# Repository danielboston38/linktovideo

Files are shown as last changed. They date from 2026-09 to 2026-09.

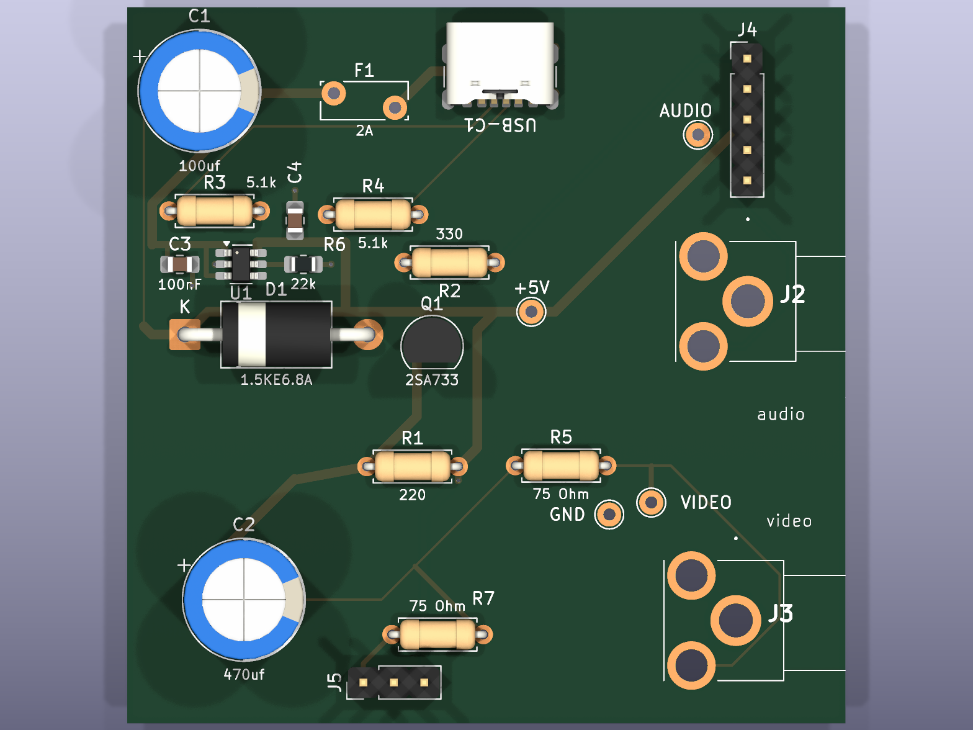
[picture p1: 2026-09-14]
pcb_top_final.png

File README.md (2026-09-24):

# Link to Video

A replacement for the RF modulator in the original Nintendo Entertainment System (NES-001). Drops into the stock RF module slot inside the shell and provides composite video and USB-C power in place of a part that fails by design.

<a href="https://certification.oshwa.org/us002842.html">
  OSHWA Certified Open Source Hardware UID US002842
</a>

> [!CAUTION]
> **Safety advisory for boards built before 2026-09-08.**
> On every board fabricated so far, the USB-C VBUS input reaches F1 through 9.06 mm of
> 0.2 mm-wide trace. That trace fails at a current well below F1's guaranteed trip
> current. If a fault occurs downstream, **F1 cannot protect the input trace on the
> board**.
> The defect has no effect on normal operation (48 °C, 17 mV drop). It is a
> fault-tolerance defect, not a wear-out defect: a board that works now will keep working.
> Commit [`247334c`](../../commit/247334c) corrects the layout. Reworking an affected
> board takes about 15 minutes.
>
> **→ Read the full advisory: [docs/SAFETY-ADVISORY-2026-09-vbus-trace-ampacity.md](docs/SAFETY-ADVISORY-2026-09-vbus-trace-ampacity.md)**

> **Renamed.** The first revision of this project was called **Kirby's New Dream**.
> From v2 on, it is **Link to Video**. Anything carrying the old name is the same
> project: the v1 board silkscreen, the 2026-07-16 PCBWay fab package, and older commits.
> The GitHub repository has been renamed too, and the old `kirbysnewdream` URL still
> redirects to it.

## Why this board exists

The NES-001's RF modulator already carries composite video, so this isn't about
adding an output the console lacks. It's about replacing a part that reliably
destroys itself.

Nintendo packed the modulator's regulator and RF stages into a sealed can with no
ventilation. It cooks its own electrolytics, they leak, and the electrolyte eats
the traces underneath. Across three NES-001 units on the author's bench, **all
three** had modulator failures from exactly this — including a Mitsumi unit that
looked pristine externally and had every capacitor leaking inside.

So the modulator is a consumable on a forty-year-old console, and the usual
options are to recap a corroded board or to fit an aftermarket board. This is the
second option, with the power input modernised to USB-C while the slot is open.

## Disclosure

This project's schematic design, debugging, and documentation were developed with the assistance of AI (Claude, by Anthropic). All hardware was hand-assembled, tested, and validated by the author. Use, review, and verify independently before building.

## Status

🟡 First prototype assembled and power-tested successfully (5V confirmed clean on rail, no protection trips). Video output path **does not work on v1 hardware** — traced to a schematic defect in which Q1's emitter node was shorted to the +5V rail (see Known Issues). Fixed in source; v1 boards need a rework.

<!-- Swap the line above for something like this once video's confirmed:
🟢 Fully validated — power and composite video both confirmed working on hardware.
-->

## Features

- USB-C power input (power only, no data lines)
- Composite video output
- Active overcurrent protection: TPS2553 eFuse with a ~1.18 A resistor-programmed limit, soft-start and thermal shutdown, and a polyfuse as backup
- Fits inside the original NES shell at the stock RF module location
- Bring-up test points for video, ground, +5 V and audio, labeled on the silkscreen
- Header that feeds an external 8-pin mini-DIN RGB connector (NESRGB)
- All resistor and capacitor values printed on the silkscreen (v1 had four identical, unlabeled axial footprints holding four different values, which led to three wrong-resistor build errors)
- 2-layer PCB, designed in KiCad

## Power path

```
USB-C  ──  F1 polyfuse  ──  U1 TPS2553 eFuse  ──  +5V rail  ──  J4.3 → NES
  VBUS      2.0A hold        ~1.18A limit          C1 100µF
            3.8A trip        soft-start            D1 TVS
            (backup)         thermal shutdown
```

F1 doesn't trip until 3.8 A, and the console only draws about 0.5–0.7 A, so on its
own F1 protects almost nothing. U1 does the real work. F1 is there in case the eFuse
fails short.

R6 on U1's ILIM pin sets the current limit. The relationship is
**inverse**: a larger resistor gives a *lower* limit.

| R6 | Limit (typ) |
|---|---|
| 15 kΩ | 1700 mA |
| 20 kΩ | 1295 mA |
| **22 kΩ (fitted)** | **~1180 mA** |
| 49.9 kΩ | 520 mA |
| 210 kΩ | 130 mA |

As a rule of thumb, I_OS(A) ≈ 25.9 / R6(kΩ), valid across TI's recommended range of
15 kΩ–232 kΩ.

U1's EN (pin 3) is active-high and tied to U1's own input, so the switch is always on.
FAULT (pin 4) is open-drain and left unconnected, since nobody can see an indicator
inside a closed NES shell. If you want a fault LED anyway, FAULT can sink 25 mA directly.

**Useful side effect: a reversed D1 is survivable.** D1 is a unidirectional TVS, so
installing it backwards puts a forward-biased diode straight across the 5 V rail.
Before the board had U1, that was a near-dead short, with only the polyfuse (which
takes seconds to react) in the way. Now the eFuse holds the current to ~1.18 A and
then shuts down thermally, so the mistake limits itself instead of destroying parts.

## Test points (v2)

The board has four through-hole test points (2.0 mm pad, 1.0 mm drill) for bring-up.
Each takes a 0.64 mm square header pin, so you can solder pins in and hang scope
grabbers off them.

The silkscreen shows only the signal name (`VIDEO`, `GND`, `+5V`, `AUDIO`), so you
can read the board without this table. The reference designators are on F.Fab, for
the fab drawings.

The first pass of v2 had this backwards: the signal names were on F.Fab, which never
reaches the physical board, so the silkscreen showed only `TP1`–`TP4`.

| TP  | Net | Location (mm) | Notes |
|-----|---|---|---|
| TP1 | `/VIDEO_OUT` | 62.0, 60.0 | Jack-side video, after C2 and the 75 Ω series resistor R5. This is what the TV sees. A high-impedance probe reads roughly double the terminated amplitude. |
| TP2 | `GND` | 58.5, 60.0 | Connects directly to the B.Cu ground pour. |
| TP3 | `/5V` | 52.0, 43.1 | On the protected 5 V trunk, downstream of F1 and the TPS2553. |
| TP4 | `/AUDIO_OUT` | 65.9, 28.35 | Audio pass-through between J4 pin 2 and J2. |

TP2 is just a convenience. The whole back layer is ground pour, so any B.Cu feature
works for a ground clip.

To probe the buffer itself rather than its output, go straight to Q1's emitter leg.
`Net-(Q1-E)` has no test point.

## RGB output (v2)

This board can feed the RGB connector for the [NESRGB](https://etim.net.au/nesrgb/)
board, which uses the 8-pin mini-DIN pinout of the Micomsoft XRGB-mini Framemeister.

The connector itself is **not** on this board. It comes with the NESRGB kit as a
panel-mount jack that is epoxied into a 12 mm hole in the shell. R/G/B run straight
from the NESRGB to that jack, and **J5** on this board supplies the other three pins:

| J5 pin | Net | mini-DIN pin | |
|---|---|---|---|
| 1 | `/RGB_VIDEO` | 3 | Composite video / sync, 75 Ω terminated |
| 2 | `GND` | 4 | |
| 3 | `/5V` | 5 | Downstream of the TPS2553, so it is current-limited |

Mini-DIN pins 1 and 2 are unconnected. Pins 6, 7 and 8 are Blue, Green and Red from
the NESRGB. The pinout carries no audio, so audio stays on the RCA jack. That was a
deliberate choice by Tim Worthington, to keep video noise out of the audio.

**Why R7 exists.** The output of the video buffer (`/VIDEO_BUF`, Q1's emitter
through C2) now feeds two outputs, and each needs its own 75 Ω source termination:
R5 for the RCA jack, R7 for the mini-DIN. A single shared resistor would put two
75 Ω loads in parallel whenever both cables were plugged in, halving the amplitude.

**One output at a time.** Composite and RGB are alternatives, and the design doesn't
target using both at once. Whichever cable is plugged in sees a correct 75 Ω source,
and the unused branch is just an unloaded stub.

If both cables are plugged in anyway, R7 still gives each output a correctly
terminated 75 Ω source, and the amplitude doesn't halve. The limit then becomes Q1's
drive, which is why **R1 is 220 Ω from v2**, down from the original 330 Ω.

In an ngspice simulation with 2 Vpp at the tap and both outputs terminated, the
follower clips the positive (white) peaks by 33 % at 330 Ω and by 11 % at 220 Ω.
With one output loaded (the supported mode), 220 Ω is clean and symmetric
(+0.439 / −0.447 V at the jack). These are simulated numbers, not bench
measurements, and driving both outputs is still unsupported.

## Hardware

- Designed in KiCad (schematic + PCB source included in this repo)
- Fabricated by PCBWay
- See [BOM.csv](./BOM.csv) for the full parts list

### Sponsored by PCBWay

The most recent fabrication run of this board — the 2026-08-26 package, ordered
**2026-08-27** — was
**sponsored by [PCBWay](https://www.pcbway.com/)**, who covered the manufacturing
of the boards this project is built and tested on. Thank you — having the fab
covered is what let this revision get made, populated and put on the bench rather
than staying a set of gerbers.

Those boards predate [`247334c`](../../commit/247334c), so like every board
fabricated so far they carry the `/raw_5v` trace-ampacity defect described in the
caution at the top of this file — see
[the safety advisory](docs/SAFETY-ADVISORY-2026-09-vbus-trace-ampacity.md).

PCBWay have been good to work with on the practical side too: the 2-layer,
1.6 mm FR4 board here is an unremarkable order for them, the gate-generated fab
package uploaded without any back-and-forth over the drill or layer files, and
they will run the four SMD lines (C3, R6, U1, USB-C1) as single-sided SMT while
leaving the through-hole parts to the bench — including sourcing the TPS2553
from LCSC, which DigiKey and Mouser have on a 112-day lead. See
[docs/pcbway-smd-assembly.md](./docs/pcbway-smd-assembly.md) for that workflow.

The project is also published on PCBWay's community site, with the same design
files and documentation as this repository:

**→ [Link to Video on PCBWay Community](https://www.pcbway.com/project/shareproject/Link_to_video_7f1f9279.html)**

The sponsorship covered fabrication only, and carries no editorial influence over
this documentation. The design remains [CERN-OHL-S v2](./LICENSE.txt) and
OSHWA-certified, free for anyone to study, modify, build and have made wherever
they like. The PCBWay-hosted copy is published under GPL v3 because their form
does not offer CERN-OHL-S — see [License](#license).

## Build Notes / Known Issues (v1)

- **Q1 emitter node shorted to +5 V (breaks video).** The rail clamps Q1's emitter,
  so C2 couples +5 V, not video, into R5/J3.

  The exact wiring differs between revisions. In the pre-v1.1 source in this
  repository, R1 had *both* ends on `/5V`. On the boards fabricated from the
  2026-07-16 gerbers, R1 pad 1 is on `/5V` and pad 2 is on a separate net with only C1.

  Root cause: an edit on 2026-07-04 deleted an R2 (110 Ω) from the schematic, and
  KiCad merged the two leftover collinear wire stubs into a single wire that tied the
  emitter node to `/5V`. The source is fixed as of v1.1. To rework an existing board,
  see [Q1 emitter rework (v1 boards)](#q1-emitter-rework-v1-boards).
- The mounting holes of the RCA jack are slightly asymmetric. This is cosmetic and
  doesn't affect the fit in the NES shell.
- The v1 silkscreen has no component values and no E/C/B markers for Q1.
  **v2 adds the values.** R1/R3/R4/R5/R7 share one footprint across four values, and
  on v1 that led to three wrong-resistor errors in R1: a 5.1 kΩ and an 820 Ω both
  went in before the correct value. Q1 pin markers are still missing.
- **VBUS input trace is undersized for its own fuse (all fabbed boards).** `/raw_5v`
  reaches F1 through 9.06 mm of 0.2 mm trace. At 2.22 A the trace heats past the glass
  transition of FR4, and at 2.83 A it chars. F1 (RHEF200) is guaranteed to hold up to
  2.0 A but only guaranteed to trip above 3.8 A, so in the 2.2–3.8 A window the trace
  can burn out before the fuse ever opens.

  Root cause: a gap in the netclass patterns. `/5V*`, `GND*` and `VBUS` were assigned
  the `Power` class (0.8 mm), but none of them matched the actual net name `/raw_5v`,
  so it fell through to `Default` (0.2 mm). DRC can't catch this, because it enforces
  the board's `min_track_width` (0.2 mm), not the netclass width. Commit `247334c`
  fixes the pattern and reroutes the trace at 0.8 mm.
  **Existing boards need a rework.** See
  [the safety advisory](docs/SAFETY-ADVISORY-2026-09-vbus-trace-ampacity.md).

- **D1 does not protect U1.** The installed TVS is a Littelfuse 1.5KE6.8A: stand-off
  5.80 V, breakdown 6.45–7.14 V at 10 mA, clamping 10.5 V at 144.8 A. The TPS2553's
  absolute maximum on IN and OUT is 7 V, which is where the TVS is only just starting
  to conduct. In a real surge, it lets the rail reach 10.5 V. D1 protects the console
  downstream, but not U1.

  Moving D1 wouldn't help, since both U1 pins share the same 7 V rating, and no
  avalanche TVS both clamps below 7 V and stands off USB-C's 5.5 V worst case. The
  real fix is a switch with a built-in overvoltage cutoff. That's a v3 change; v2
  ships with this gap.
- D1's symbol (`Diode:1.5KExxA`) labels its pins A1/A2 and shows no cathode, because
  KiCad uses the same pin names for the unidirectional and bidirectional variants of
  this part. Only the footprint's silkscreen band shows the polarity. The band is at
  the pad-1 (+5 V) end, which is correct, so go by the band when you assemble by hand.

### Q1 emitter rework (v1 boards)

This applies to boards fabricated from the 2026-07-16 gerbers, whose IPC netlist
reads:

- `/5V = J4.3, F1.1, R1.1, Q1.1, C2.1, D1.1`
- `Net-(C1-Pad1) = R1.2, C1.1`

That revision has two defects:

- The rail clamps Q1's emitter.
- C1 only reaches the rail through R1, so the bulk capacitor isn't decoupling the
  rail.

This procedure fixes both at once.

> [!CAUTION]
> **Do not power the board with Q1 installed until the cut is done.** This short kills transistors.
> With the emitter clamped at +5 V and the base at the NES video level, the B-E
> junction is forward-biased by 3–4 V. Q1 saturates into a collector tied straight to
> ground, and nothing limits the current: Q1 is a 150 mA part, and F1 won't trip until
> 3.8 A. Every power-up in that state can take out another transistor, which is
> probably how the first one died.

**Confirm the diagnosis before you cut.**

1. Disconnect the power.
2. Make sure the capacitors are discharged.
3. Put one meter lead on +5 V, at J4 pin 3 or at D1's K-marked lead.
4. Take the two measurements in the table. A defective board and a correct board
   give opposite results:

| Measurement | Defective board | Correctly wired |
|---|---|---|
| Q1 emitter → +5 V | **~0 Ω** | ~330 Ω (R1) |
| C1 **+** terminal → +5 V | **~330 Ω** (stranded behind R1) | ~0 Ω |

After the rework, the two readings swap.

To identify Q1's legs without relying on the TO-92 orientation, measure each leg:

- 0 Ω to GND: collector
- Continuity to J4 pin 1: base
- The remaining leg: emitter

Two tests look useful but aren't:

- **Emitter → J3 tip.** C2 blocks DC, so this reads open on every board.
- **C1 + → Q1 emitter.** This reads ~330 Ω on good and bad boards alike, because R1
  sits between these two points in both wirings.

With power on, the quickest check is the DC voltage at Q1's emitter: about 1.5–3 V
on a correct board, exactly the rail voltage on a shorted one.

**R1's left pad is a star point.** Three connections meet there:

- F1 (the source)
- The D1 + J4.3 branch (the load)
- Q1's emitter

The two incoming rail traces are *collinear*, so one cut severs both. That's why the
rework needs **two** jumpers, not one.

1. **Cut** the 0.8 mm trace that runs from R1's left pad toward the **upper
   left**, about 5–8 mm from the pad.

   Leave the trace coming in from the upper right alone. That one is Q1's emitter.

   Cut below the level of D1's cathode. Above that point, only one of the two
   overlapping traces is present, and you need to cut both.

2. **Install two jumpers.** Pull R1 first. Its right pad is much easier to solder
   when it's empty.

   The cut leaves three islands. Join all three into one rail:

   | Island | Pads |
   |---|---|
   | A | C1's **+** pad, R1's **right** pad |
   | B | F1 pad 1 (left pad, trace toward D1 — not the USB-C side) |
   | C | D1's cathode (K), J4 pin 3 |

   Any two wires that join all three islands will work. For example, with one wire
   per pad:
   - **C1+ → F1 pad 1** (~14 mm)
   - **R1's right pad → D1 cathode** (~25 mm)

3. **Install R1 = 300–330 Ω.** Double-check the part before it goes in. R1, R3, R4,
   R5 (and R7 on v2) share the same `R_Axial_DIN0207` footprint across four different
   values, and the v1 silkscreen shows none of them.

   At least one board ended up with a 5.1 kΩ from the R3/R4 pile in the R1 position.
   That gives ~0.6 mA of standing current instead of ~9 mA. The board looks plausible
   but produces no usable video.

4. **Check that R5 (75 Ω) is fitted.** Measure across its pads; you should see
   ~75 Ω. R5 has no parallel path in the circuit (C2 blocks DC on one side and the
   jack is open on the other), so this doubles as a sanity check of the meter.

5. **Install the transistor last.** If you power up before the cut is complete, Q1
   saturates and the rail dumps straight into ground with nothing limiting the
   current. See the caution above.

Before you power up, check with a meter:

- R1 left pad to D1 cathode: **open**
- R1 left pad to F1 pad 1: **~330 Ω**, through R1
- R1 left pad to Q1's emitter and to C2 pin 1: continuity
- D1 cathode to J4 pin 3 *and* to F1 pad 1: **~0 Ω**

With power on, Q1's emitter should sit at about 1.5–3 V. If it reads 5 V, the cut
didn't separate the traces.

## Video input biasing

Q1's base is DC-coupled directly to the NES video line, with no bias network. That's
deliberate, and it took a long bench session to work out why it works.

**The NES mainboard supplies a 1 kΩ pulldown on its video output pin.** It measures
0.999 kΩ in circuit, the same with the meter leads either way round, so it's a real
resistor and not a semiconductor junction. Q1's base sources about 46 µA, which that
1 kΩ soaks up at about 46 mV. The base can't float up, and Q1 can't cut off.

That's also why Nintendo's original modulator has no base pulldown. It's consistent
with the load Nintendo put on that pin, too: a 330 Ω series resistor into a
5.6 kΩ / 330 Ω divider, roughly 500 Ω in total. The NES is designed to drive a few
hundred ohms.

**So this board has no base pulldown and no input coupling capacitor.** If you
adapt this design for something other than an NES-001, measure that pin to ground
first, and if it reads open, add a pulldown (~47 kΩ).

**R2 (330 Ω) is not a bias resistor.** It sits in series between J4 pin 1 and Q1's
base, in the same position as Nintendo's own 330 Ω. Against Q1's ~21 kΩ base input
impedance it has almost no effect on the signal. Its job is to limit fault current
into the base-emitter junction, which is only rated for 5 V in reverse.

## Design checks

Beyond ERC and DRC, this project runs three more checks. The first two catch faults
this board actually shipped with. The third closes the gap between checking a board
and fabricating it.

### `tools/check_nets.py`

```
python3 tools/check_nets.py
```

The script exports the schematic netlist, reads the pad nets from the PCB, checks
that the two agree, and then asserts a set of invariants.

The most important invariant is that **Q1's emitter is not on any power net**.
That was the v1 fault: the emitter follower's output was tied to +5 V along with
J4.3, D1.1 and F1.1, so Q1 saturated into a grounded collector with nothing limiting
the current. Every power-up killed a transistor.

**ERC and DRC both passed on that board with no errors.** Neither can tell that a
net is *wrong*, only that it's internally consistent. That's why this script exists.

Run it before you generate a fab package. Gerbers carry no net information, so once
they're generated the mistake is invisible.

### `nes_power_video.kicad_dru`

Custom DRC rules for the geometric half of the problem:

- More clearance between the supply rails and the emitter and base nodes
- More clearance between the two USB-C configuration channels

These catch the same class of mistake when it shows up as adjacent copper in the
layout. They can't catch a wrong net assignment, because DRC knows nothing about
design intent. That's what the script above is for.

### `prefab-gate`

```
export KICAD_CLI=/Applications/KiCad/KiCad.app/Contents/MacOS/kicad-cli
prefab_gate package nes_power_video.kicad_pcb --out pcbway_production
```

**prefab-gate now lives in its own repository:
[danielboston38/prefab-gate](https://github.com/danielboston38/prefab-gate).**
It's a general-purpose KiCad tool with its own MIT license and users beyond this
project, so it moved out of this hardware repo.

You can install it any of these ways:

- As a KiCad plugin, through the Plugin and Content Manager
- As a Claude Code plugin: `/plugin marketplace add danielboston38/prefab-gate`
- By cloning the repository and running `scripts/prefab_gate.py` directly

The gate refuses to write a fab package unless the board passes both DRC with zone
refill *and* schematic parity. It hashes the board and the schematic after the
refill and checks them again right before publishing, so the package always
describes the board the gate actually verified. `manifest.json` records the result
along with every finding, including the cosmetic findings the gate waived.

To get the verdict without writing files, run `check` instead of `package`.

`pcbway_production/` isn't tracked in git, since the packages can be regenerated
from the board. The first two fab packages are still in the git history, at the
2026-07-07 and 2026-07-16 commits. The 2026-08-26 package for the sponsored run was
never committed, but its copper and outline gerbers have been checked byte-identical
to the board at [`f672f8d`](../../commit/f672f8d), and all 49 drill hits match.

When you order, generate a fresh fab package rather than reusing an old directory,
so the gate re-verifies the exact board you're paying for.

## Assembly

<!-- Add step-by-step or reference photos here once you've got a documented build process -->

See BOM.csv for the exact part values and footprints. Every component's sourcing
data lives in two places, and the two agree:

- The `Manufacturer`, `MPN`, `LCSC`, `Supplier Link` and `Datasheet` fields on the
  schematic symbol
- The matching columns in `BOM.csv`

Generic passives deliberately have no manufacturer part number. They carry a `Spec`
field instead (tolerance, rating, package), and any part that meets it will do. To
pull the fields straight from the schematic:

```
kicad-cli sch export bom --group-by '' \
    --fields 'Reference,Value,Manufacturer,MPN,LCSC,Datasheet,Supplier Link,Spec' \
    -o bom.csv nes_power_video.kicad_sch
```

The `Mount` column in `BOM.csv` marks each line `SMD` or `THT`, taken from the
footprint attributes on the board.

### Having PCBWay fit the SMD parts

Only four parts need reflow — C3, R6, U1 and USB-C1 — and all four are on the top
side. PCBWay can do those as single-sided SMT while you hand-solder the 15
through-hole parts. That way you skip the two hardest joints on the board (the
SOT-23-6 and the Type-C receptacle) without paying for full assembly.

`tools/pcbway_assembly.py` builds the SMD-only upload pair from a gate-generated fab
package. It takes the SMD/THT split from the board, not from a hand-maintained list:

```
python3 tools/pcbway_assembly.py nes_power_video.kicad_pcb pcbway_production/<timestamp>
```

Two things to know before you order:

- **U1 is out of stock at both DigiKey and Mouser** (112-day factory lead). LCSC has
  44,000, so tell PCBWay to source U1 from LCSC.
- **USB-C1 is Hybrid, not SMD.** Its four shell stakes are through-hole pads on the
  paste layer, and they must reflow pin-in-paste with everything else. Don't leave
  them dry.

As of v2, all four SMD lines (C3, R6, U1, USB-C1) are LCSC parts, so PCBWay can source
the whole assembly BOM from LCSC. For the full workflow, including what to upload and
what not to, see **[docs/pcbway-smd-assembly.md](./docs/pcbway-smd-assembly.md)**.

Key notes:
- D1 (zener/TVS): put the cathode (banded end) toward the VBUS/+5V side. From v2, the
  silkscreen shows the actual part, `1.5KE6.8A`. Earlier boards show KiCad's generic
  symbol name, `1.5KExxA`, which isn't an orderable part.
- Q1 (**2SA733**, PNP): with the flat side facing you and the leads down, the pins are
  Emitter-Collector-Base, left to right.
  This replaces the 2SA1015/KSA1015, **both of which are end of life** (checked 2026-08-29): MCC's
  `2SA1015-GR-AP` is stocked at Mouser but flagged End of Life, and every onsemi `KSA1015` reads
  Obsolete on DigiKey, available only through Rochester Electronics' last-time-buy channel. The
  2SA733 is in current production, shares the E-C-B pin order exactly so it drops straight in, and is
  a better part for a video buffer: f_T 190 MHz typ against the 2SA1015's 80 MHz, C_ob 2–3 pF, P_C
  750 mW, with the same V_CEO −50 V / I_C −150 mA / V_EBO −5 V — so R2 still guards the base-emitter
  junction exactly as before. Buy the UTC `2SA733L-P-T92-B` from LCSC (**C5310429**, ~$0.035).
  Rank P is hFE 200–400, which matches the ~46 µA base current measured on the bench, so the bias
  point does not move. DigiKey's Renesas 2SA733 is Rochester stock at $1.90 — same trap, different part.
- **Why not a 2N3906 or BC557?** Not for the reason you might assume. Electrically the 2N3906 is
  perfectly happy here — V_CEO −40 V, I_C −200 mA, f_T 250 MHz, V_EBO −5 V, hFE 100–300 at 10 mA,
  every figure with huge margin against a 5 V rail at ~9.3 mA. The problem is the middle pin. Per
  UTC's ordering tables, the 2N3906 is **E-B-C** and the 2SA733 is **E-C-B**: the 3906 puts *base* in
  the centre where this board wants *collector*. Turning the part around gives C-B-E — base is still
  in the middle, so no orientation fixes it and you would have to cross two leads. On a v3 layout the
  pin order is free and the 2N3906 becomes a fine choice; on this board it is not. Pin order is a
  manufacturer's choice rather than a standard, so check the datasheet of the exact brand you buy.
- R1 (220 Ω): Q1's emitter load. One end goes to +5 V and the other to the Q1 emitter /
  C2 node; both ends on +5 V is wrong. v2 dropped R1 from 300 Ω to 220 Ω for more
  drive current. Assuming ~1.3 V at the base, 300–330 Ω gives only ~6.2 mA at peak
  white, and the 150 Ω load needs ~6.7 mA. If you measure something other than ~1.3 V
  DC at J4 pin 1, recalculate R1.
- R2 (330 Ω): series resistor in the video input line, between J4 pin 1 and Q1's base. See [Video input biasing](#video-input-biasing).
- **Trim all through-hole leads flush.** The board sits in the RF module slot with
  shielding directly underneath, and long leads on the bottom side will short to the
  can. On the prototype, this caused an intermittent supply trip that only happened
  when the board moved.
- C2 (470 µF): not 100 µF. Into the 150 Ω load, 100 µF gives τ=15 ms against a
  16.7 ms field period, so the picture tilts from top to bottom. 470 µF gives τ=70 ms.
- F1 (polyfuse): it's fine for it to sit slightly off the PCB. That's normal for
  radial-lead parts, not a defect.

  **KiCad has no footprint for the Littelfuse RHEF series.** F1 borrows
  `Fuse:Fuse_Bourns_MF-RG300`: pads 5.24 mm center-to-center, with 1.01 mm drills. The
  RHEF200's 0.51 mm leads at 5.05 ±0.75 mm spacing fit easily. But the Bourns part is
  rated 3.0 A/5.1 A and the silkscreen outline shows *its* body, so treat the outline
  as a rough guide, not a clearance boundary. A proper RHEF200 footprint moves pad 2 by
  ~1.2 mm and needs a reroute, so that's a v3 change rather than a patch.

  **F1 stays a Littelfuse RHEF200 and is deliberately not an LCSC part.** It's
  through-hole, so it isn't on the SMD assembly BOM that PCBWay sources anyway, and
  the LCSC alternatives are worse where it matters:
  - Jinrui JK30-200 (C369104): I_max drops to 40 A, and the part is 15.2 mm tall.
  - JKSEMI JK16-200T (C5183874): LCSC lists it as through-hole, but its datasheet is
    titled *"JK16 Series Surface Mount PTC Devices"* and shows no land pattern, so its
    package is unconfirmed.

  If you need to reorder F1, get it from DigiKey or Mouser along with the Switchcraft
  RCA jacks, which LCSC can't supply either.
- USB-C1: GCT USB4125-GF-A-0190, SMD receptacle. Power-only, 6P, no data lines,
  48 V / 3 A, 20,000 mating cycles.

  **As of v2, this part replaces the GCT USB4970-00-A**, which LCSC doesn't stock (a
  search for that MPN turns up nothing). The USB4125 is a different GCT line that LCSC
  *does* stock (C5246813). The board already used its land pattern, so this is a
  sourcing change only, not a layout change.

  The footprint is `Connector_USB:USB_C_Receptacle_GCT_USB4125-xx-x-0190`. Its copper,
  silk, fab, courtyard and drills are byte-identical to the plain `USB4125-xx-x`
  variant the board used before; only the name, the descr field and the 3D model
  differ.

  Use the **-0190** variant. Its 1.90 mm shell stake pokes 0.30 mm through this 1.6 mm
  board and gives a fillet on the bottom side. The 1.00 mm stake (plain
  `USB4125-GF-A`, C3151650) doesn't make it through. LCSC stocks fewer of these than
  of the generic Chinese 6P parts, so order spares.
- U1 (TPS2553, SOT-23-6): pin 1 (marked by the dot on the package) is IN. The pins run
  IN, GND, EN down one side and OUT, ILIM, FAULT up the other. Order the plain
  TPS2553DBVR. The `-1` suffix is the latch-off variant, which needs a power cycle
  after every trip; the plain part retries automatically.
- C3 (100 nF, 0805): TI wants C3 as close to U1 pin 1 as the layout allows. It sits
  immediately to the left of U1.
- R6 (22k, 0805): sets the current limit. Check the table in
  [Power path](#power-path) before you change it.

## Certification

This project is **OSHWA-certified open source hardware**, UID **[US002842](https://certification.oshwa.org/us002842.html)**.

The certification confirms that the design files, schematics, PCB layout, bill of
materials and documentation in this repository:

- Are published under an OSI/FSF-approved open license
- Are complete enough for someone else to study, modify, manufacture and distribute
  the hardware

See the [OSHWA certification directory entry](https://certification.oshwa.org/us002842.html)
for the registered details.

The certification mark above,
[`certification-mark-US002842-stacked.svg`](./certification-mark-US002842-stacked.svg),
was issued by OSHWA for this UID. It applies only to this design and doesn't transfer
to derivatives; each derivative needs its own certification.

## License

Licensed under [CERN-OHL-S v2](./LICENSE.txt) (strongly reciprocal open hardware license). See [LICENSE](./LICENSE.txt).

**The PCBWay community copy is GPL v3.** PCBWay's project form doesn't offer
CERN-OHL-S, so the copy
[on their community site](https://www.pcbway.com/project/shareproject/Link_to_video_7f1f9279.html)
is licensed GPL v3. Same design, same files, two license grants: use whichever one
you received the design under. Both licenses are copyleft and both are on the
approved list, so the certification holds either way.

The practical difference is the physical board. CERN-OHL-S covers the *making* of
hardware: if someone builds and sells a board, the complete source has to go with
it. GPL v3's copyleft kicks in when someone distributes the design files, so it
doesn't reach a board fabricated from them. Both licenses keep the design files
reciprocal; only CERN-OHL-S extends that to manufactured hardware.

## Photos

<!-- Add build photos here -->

## Acknowledgments

- **[PCBWay](https://www.pcbway.com/)** — for sponsoring the fabrication of the
  latest revision of this board, and for hosting the project on their community
  site: [Link to Video](https://www.pcbway.com/project/shareproject/Link_to_video_7f1f9279.html).
- **Tim Worthington** — for the [NESRGB](https://etim.net.au/nesrgb/), whose
  8-pin mini-DIN pinout J5 on this board feeds.
- **OSHWA** — for the open hardware certification programme
  ([US002842](https://certification.oshwa.org/us002842.html)).

<!-- Optional: credit anyone who helped with debugging, Discord community, etc. -->

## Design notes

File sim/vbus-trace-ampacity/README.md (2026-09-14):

# VBUS trace ampacity — simulation harness

Reproduces every simulation figure quoted in
[`docs/SAFETY-ADVISORY-2026-09-vbus-trace-ampacity.md`](../../docs/SAFETY-ADVISORY-2026-09-vbus-trace-ampacity.md).

Published so the advisory's claims can be checked independently rather than taken on
trust. If you are reviewing this — including with another AI — the useful thing to
attack is the **model**, not the arithmetic; see *Assumptions worth challenging* below.

## Run it

```bash
brew install ngspice          # or: apt install ngspice
python3 run_all.py
```

Python 3.10+, standard library only. Runtime is about two minutes; ngspice must be on
`PATH`. Output is five sections matching the advisory.

Every ngspice deck is kept, under `./vbus_sim_decks/` (override with `--decks DIR`).
There are ~394 of them, about 7 MB. They are named so the deck behind any published
figure can be found directly — `012_steady_asfabbed_2.000A.cir` is the 105 °C headline,
and the `damage_asfabbed_130C_*.cir` series shows the search converging on 2.22 A. The
directory is gitignored; delete it with `rm -rf vbus_sim_decks`.

## What's here

| File | Purpose |
|---|---|
| `thermal_model.py` | The electrothermal model and its IPC-2221 calibration |
| `extract_geometry.py` | Pulls trace geometry by connectivity from `.kicad_pcb` **and** from Gerbers |
| `run_all.py` | Runs every scenario and prints the report |

## The model

The trace is discretised along its length into 0.25 mm slices. Each slice has:

- **Electrical** — a behavioural resistor `R(T) = ρ·dx/(w·t) · (1 + α(T−20))`
- **Thermal** — copper node → *spreading resistance* → near-FR4 node → *bulk* → ambient
- **Lateral** — copper-to-copper thermal conduction to its neighbouring slices

The lateral term is not optional. It is what makes a short neck flanked by wide copper
survivable, and it is the entire mechanism the fix relies on. A lumped single-node model
cannot tell the pre-fix trace (one long uniform narrow run) apart from the post-fix trace
(a short neck beside wide copper) and would wrongly condemn both.

Vertical thermal resistance is calibrated so a long uniform trace reproduces IPC-2221
external-layer ampacity at its 20 K point.

## Validation

Three independent checks, all run by `run_all.py`:

1. **Against IPC-2221** — a long uniform 0.2 mm trace reproduces the standard's
   allowable current within ±8 % from 0.5–2 A, exact at the calibration point.
2. **Against Onderdonk** — the adiabatic fusing calculation gives 9.22 A for a 48 ms
   exposure; the SPICE model melts the trace in 48 ms at 10 A. ~8 % agreement from
   completely different physics.
3. **Sensitivity sweep** — thermal resistance scaled down to credit the B.Cu ground
   pour, to confirm the conclusion is not an artefact of the calibration.

## Assumptions worth challenging

Listed because they are where the analysis is weakest, not to pre-empt criticism.

- **Calibration takes no credit for the B.Cu ground pour** 1.51 mm below the trace.
  IPC-2221's external-layer curve assumes no adjacent plane, so absolute temperatures
  are pessimistic. The sensitivity sweep scales thermal resistance to 40 % of the
  calibrated value; the conclusion survives, but a reviewer could reasonably argue the
  real figure sits somewhere in that range.
- **Above ~300 °C the model is qualitative only.** FR4 decomposes, copper oxidises, and
  the thermal parameters stop being valid. Treat runaway figures as "destructive", not
  as temperatures.
- **Past the runaway knee the network has an unphysical negative-temperature root.**
  Solving `T = I²·R20·(1+αT)·Rth` gives a negative `T` once `I²·R20·α·Rth > 1`. ngspice
  returns it without complaint and it reads as *cold*. `peak()` treats any negative rise
  as runaway. A reviewer re-implementing this should reproduce that guard or they will
  get thresholds that are silently far too high.
- **1 oz copper is taken as 35 µm.** Real finished outer-layer copper after plating
  varies; thinner copper makes the result worse, not better.
- **Ambient is 25 °C.** Inside a closed NES shell it is nearer 45 °C, which lowers every
  threshold by roughly 9 %.
- **Participating FR4 volume** in the near-node heat capacity is estimated from thermal
  diffusion length, not measured. It affects transient timing, not steady-state
  temperature or any threshold.
- **The carbon-tracking secondary effect** mentioned in the advisory is reasoned from
  clearance geometry and is *not* simulated. It is the least certain claim made.

## Geometry provenance

Geometry is obtained by **walking copper connectivity**, not by measuring a bounding box.
This matters: a bounding-box measurement of the same corridor reports only 1.52 mm of
0.2 mm copper, because the route leaves the box. The connectivity walk finds the true
9.06 mm run. An early draft of this analysis made exactly that error.

The advisory quotes the **Gerber** figures, because those describe the boards as actually
manufactured. Both fabbed packages live in git history:

```
git cat-file -p 3cca8216c29fc129d4af6e3149339d9ec40d9122 > jul07.zip   # 2026-07-07
git cat-file -p 46ed2ff15eafcf9bbca26537807e6c839aaac4bc > jul16.zip   # 2026-07-16
```

Both carry an identical 9.06 mm × 0.2 mm trunk from F1 pad 2 to the USB-C VBUS pads.

## Key inputs, and where they come from

| Quantity | Value | Source |
|---|---|---|
| F1 hold current `IH` | 2.0 A | Littelfuse RHEF200 datasheet |
| F1 trip current `IT` | 3.8 A | same |
| F1 max time-to-trip | 4.3 s at 10 A | same |
| U1 current limit | 1.18 A typ, 1.26 A max | TPS2553 datasheet, `IOS` equations, R6 = 22 kΩ |
| U1 `rDS(on)` | 115 mΩ max at 25 °C | TPS2553 datasheet |
| Copper thickness | 35 µm (1 oz) | board stackup |
| Substrate | 1.51 mm FR4, 2 layer | board stackup |

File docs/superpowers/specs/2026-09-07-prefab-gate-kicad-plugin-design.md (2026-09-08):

# prefab-gate as a KiCad plugin

**Date:** 2026-09-07
**Status:** implemented and verified in KiCad 10.0.6; shipped at
[danielboston38/prefab-gate](https://github.com/danielboston38/prefab-gate).
Only the PCM registry submission (Task 8 of the implementation plan) remains.

## Why

prefab-gate is deterministic. It runs `kicad-cli` DRC with zone refill and
schematic parity, classifies each finding, and refuses to export a fab package
from a board that has not passed. No model is in the loop and none is needed —
which means the audience for it is every KiCad user, not only the ones running
Claude Code.

Today it ships one way: as a Claude Code plugin, in a subdirectory of a
hardware project about an NES video board. That is the wrong shelf. Packaging
it for KiCad's Plugin and Content Manager puts it where the people who need it
already look.

## Goals

- Run the existing gate from inside KiCad, with no command line.
- Reuse the gate's logic exactly. No second implementation of the policy.
- Never modify the user's files.
- Keep the CLI and the Claude Code plugin working unchanged.

## Non-goals

- Exporting fab packages from the GUI. See "Check only" below.
- Reimplementing DRC. The gate drives `kicad-cli`; that does not change.
- Supporting KiCad releases whose `kicad-cli` lacks the flags the gate needs.
  The existing capability probe already refuses those, with a better message
  than a version comparison would give.

## Decisions

### Check only

The toolbar button runs a check and shows a verdict. It writes nothing.

Packaging stays a CLI job because the gate's central guarantee — *what was
checked is what gets packaged* — rests on hashing a file on disk and finding it
unchanged before publishing. In the editor, the board on screen and the board
on disk can differ at any moment, and a gate that says PASS about a board the
user is not looking at is worse than no gate at all. The CLI operates on a file
nobody is editing, which is the condition the guarantee assumes.

This also keeps the plugin's surface small enough to trust.

### Its own repository

prefab-gate moves to `danielboston38/prefab-gate`, using

    git subtree split --prefix=prefab-gate

so the existing commits keep their authorship and messages instead of arriving
as a single squashed import. The tool has a different audience, a different
licence (MIT, against the board's CERN-OHL-S-2.0) and a different release
cadence from the hardware it grew up beside.

It also makes the PCM download honest: a package manager installing a 40 KB
tool should not clone a hardware project's PDFs, board images and gerber
history to do it.

**Consequence, accepted:** the board repository's README currently invokes
`python3 prefab-gate/scripts/prefab_gate.py`. After the split that path is
gone. The board repo treats prefab-gate as an external tool — installed via PCM
or cloned separately — and its documentation references `prefab_gate` on PATH.
This is the truthful description of the relationship, and it is worth a
one-time doc edit to stop pretending otherwise. A submodule was considered and
rejected: it would preserve the paths at the cost of a permanent papercut.

### SWIG ActionPlugin now, IPC later

KiCad 9.0 introduced an [IPC API](https://dev-docs.kicad.org/en/apis-and-binding/ipc-api/for-addon-developers/index.html)
that runs plugins out-of-process over a socket. It is the forward-looking
interface — stable across internal refactors, language-agnostic — and it is
explicitly *not* what this plugin uses for v0.1.

The gate runs on KiCad **8.0**, because that is when `kicad-cli pcb drc` gained
`--schematic-parity`. IPC would raise the floor to 9.0 and drop every KiCad 8
user in exchange for nothing this plugin needs. Among the 85 plugins published
in KiCad's own repository, 8.0 is the single most common floor (18 packages)
and 48 still target 7.0 or older; SWIG is not going anywhere soon, and remains
supported in 9 and 10 rather than deprecated.

What makes this a cheap decision rather than a bet: **the plugin needs exactly
one thing from KiCad — the path of the open board.** Everything else is
`kicad-cli` in a subprocess and pure-Python code of our own. That is the
smallest coupling the job admits, and the architecture below keeps every KiCad
import inside `action.py`, with a test that runs the other modules without
KiCad present to prove it. Porting to IPC rewrites one file.

IPC also runs Python plugins in an external interpreter, which leaves the
dialog an open question — a wx `MessageDialog` is an in-process assumption.
Worth resolving before a port, not before a first release.

### Run on a copy, never on the open board

DRC runs with `--refill-zones --save-board`, which rewrites the board file in
place. From a plugin, that file is the one open in the editor, and rewriting it
underneath pcbnew would leave the editor's in-memory copy silently disagreeing
with disk.

So the plugin copies the project to a temporary directory and runs there.

**The copy must include the whole project, not just the board.** Custom DRC
rules live in `<project>.kicad_dru` and severity settings in `<project>.kicad_pro`.
A copy of only the board and schematic would silently fall back to default
rules and produce a verdict that does not describe the user's design at all —
a failure mode that looks exactly like success. Files to copy:

| File | Why |
|---|---|
| `<name>.kicad_pcb` | the board |
| every `*.kicad_sch` | schematic parity; hierarchical designs have several |
| `<name>.kicad_pro` | DRC severities, which decide blocking vs cosmetic |
| `<name>.kicad_dru` | custom rules, when present |
| `fp-lib-table`, `sym-lib-table` | without them the footprint-vs-library checks cannot run |
| `${KIPRJMOD}`-relative libraries | a copied table pointing at an uncopied library is worse than no table |

**The library tables were added after measurement, not by reasoning.** Staging
without them was run against the real project and invented two
`lib_footprint_issues` findings that do not exist: kicad-cli reported the
missing `nes1` library as a finding of its own. They were cosmetic here, so the
verdict held — but a project that raises that check to error would have had a
good board blocked by its own staging. With the tables and their
project-local libraries copied, the staged verdict matches the in-place CLI
verdict exactly, which is the actual acceptance criterion.

`kicad-cli pcb drc` derives the schematic from the board's basename, so the
copy must keep the original filenames.

## Architecture

The plugin is a thin wx wrapper importing the same `gate` package the CLI
imports. The policy — what blocks, what is cosmetic, what counts as parity
having run — has exactly one implementation, already covered by 182 tests. If
the wrapper grows past roughly 150 lines, logic has leaked into it that belongs
in the library.

`subtree split` preserves paths, so `scripts/` stays where it is rather than
being flattened — no churn, and the README's commands keep working.

```
prefab-gate/
├── scripts/
│   ├── gate/                  # library, pure stdlib, unchanged
│   └── prefab_gate.py         # CLI, unchanged
├── tests/                     # unchanged, plus the new staging tests
├── .claude-plugin/            # Claude Code plugin, unchanged
└── kicad/
    ├── plugin/
    │   ├── __init__.py        # registers the ActionPlugin
    │   ├── action.py          # wx dialog, verdict rendering
    │   ├── staging.py         # assemble the temp project copy
    │   └── icon24.png         # toolbar icon, 24x24
    ├── icon.png               # PCM listing icon, 64x64
    ├── metadata.json          # PCM manifest (no download_* fields)
    └── build_pcm.py           # builds the zip, emits sha256 and sizes
```

`staging.py` is separated from `action.py` deliberately: deciding which files a
project needs is the part with real consequences, and as a pure function over a
directory listing it is testable with no KiCad and no GUI present. The wx code
around it stays dumb enough not to need tests.

### Flow

1. `pcbnew.GetBoard().GetFileName()` gives the project path.
2. `staging.collect()` returns the file list; refuses if the board has never
   been saved, or if no schematic sits beside it under the board's basename.
3. Copy into a `TemporaryDirectory`.
4. Call the existing check entry point on the copy.
5. Render the verdict; delete the temp directory.

## What the dialog must say

Two things are not optional, because both are cases where a quiet plugin would
mislead.

**Which file it read.** Detecting unsaved editor changes from a plugin is
unreliable, so the plugin does not guess. It states the path and mtime of the
board it checked and lets the user resolve the ambiguity. A heuristic that is
right most of the time is the wrong tool for a guarantee.

**That stale zone fills were reported, not repaired.** The CLI refills and
saves, so it fixes staleness as a side effect. A read-only plugin cannot. When
the board hash changes during the refill on the copy, the verdict says so
explicitly — *your zone fills are stale; refill and save before exporting* —
because a clean PASS on a board whose on-disk fills are stale is precisely the
fault this gate exists to catch.

The verdict otherwise mirrors the CLI: pass or blocked, blocking findings
first, cosmetic ones listed but marked waived, and the count of check
categories disabled in project settings.

## Packaging

Per KiCad's [addon developer documentation](https://dev-docs.kicad.org/en/addons/index.html),
the package is a **ZIP** (ISO 21320-1 compatible) laid out as:

```
metadata.json          at the archive root
plugins/               plugin code, plus the 24x24 toolbar icon
resources/icon.png     64x64, the PCM listing icon
```

Two icons are needed, not one: 64×64 at `resources/icon.png` for the manager's
listing, and a separate 24×24 inside `plugins/` for the pcbnew toolbar button.

`build_pcm.py` assembles the archive from `kicad/plugin/` plus the `gate`
package, and computes `download_sha256`, `download_size` and `install_size`.
Generating them is the point: three numbers describing an artifact, maintained
by hand, drift from it.

**The `download_*` fields must be absent from the `metadata.json` inside the
archive.** They belong only to the copy submitted to the metadata repository.
Shipping them in the package is a spec violation, and an easy one to make by
copying one file to both places.

### Manifest values

Validated against the [v2 schema](https://gitlab.com/kicad/code/kicad/-/raw/master/kicad/pcm/schemas/pcm.v2.schema.json),
which is authoritative where it and the prose documentation disagree — and they
do: the docs say `description` is capped at 150 characters, the schema says 500.

Required at top level: `name`, `description`, `description_full`, `identifier`,
`type`, `author`, `license`, `resources`, `versions`. **`resources` is required**,
which the prose reads as optional; it is an object of link name to URL, so
`{"homepage": "https://github.com/danielboston38/prefab-gate"}` satisfies it.

| Field | Value | Schema constraint |
|---|---|---|
| `identifier` | `com.github.danielboston38.prefab-gate` | `^[a-zA-Z][-a-zA-Z0-9.]{0,98}[a-zA-Z0-9]$` — dots allowed, ≤100 chars |
| `type` | `plugin` | `^[a-z][-a-z0-9]{0,48}[a-z0-9]$` |
| `license` | `MIT` | GPL-compatible, as required for Python plugins |
| `kicad_version` | `8.0` | `^\d{1,2}(\.\d{1,2}(\.\d{1,2})?)?$` |
| `status` | `testing` first, `stable` once it has seen use | one of stable/testing/development/deprecated |
| `tags` | reuse the Claude Code plugin's keywords | `^[a-z][-a-z0-9]{0,49}$`, unique, ≥1 item |

Each `versions[]` entry requires `version`, `status` and `kicad_version`.

**Release versions cannot carry a pre-release suffix.** `version` must match
`^\d{1,4}(\.\d{1,4}(\.\d{1,6})?)?$`, so `0.1.0` is fine and `0.1.0-beta` is
rejected. Pre-release intent is expressed through `status: testing`, not the
version string — worth knowing before tagging.

`kicad_version` is 8.0 because `kicad-cli pcb drc` — with `--schematic-parity`
and JSON output — [arrived in KiCad 8.0](https://www.kicad.org/blog/2024/02/Version-8.0.0-Released/).
The gate's runtime capability probe is still the real check and gives a better
message than a version comparison; the manifest number just stops PCM offering
the plugin to KiCad 7 users who could never run it.

The identifier should match the repository name for a single-package repo —
which the split gives us for free.

**Licence check passes:** KiCad requires Python plugins to be under a
GPL-compatible open-source licence. prefab-gate is MIT, which qualifies.

### Submission

A merge request to `https://gitlab.com/kicad/addons/metadata`, adding
`packages/com.github.danielboston38.prefab-gate/` containing `metadata.json`
and the icon. **Not** `addons/repository`, which the docs explicitly say not to
submit to. Until the MR lands, the same zip installs via PCM's *install from
file*, so the plugin is usable before it is listed.

KiCad also requires the source to be hosted somewhere with issue tracking — a
further reason the split is necessary rather than merely tidy — and reserves
the right to remove packages with unresolved bugs after 90 days. That is a real
maintenance commitment, not a publish-and-forget.

KiCad-Diff was examined as a reference. Its plugin code is a reasonable shape
to follow; its packaging is not — it ships a tarball of a `plugin/` folder and
points the manifest at a GitHub archive URL, which is why installing it costs
21 MB.

## Testing

The existing suite is untouched and keeps its meaning: it covers the logic the
plugin calls.

New tests cover `staging.collect()` — that it gathers every `.kicad_sch` rather
than only the root sheet, includes `.kicad_pro` and `.kicad_dru` when present,
tolerates `.kicad_dru` being absent, preserves basenames, and refuses an
unsaved board. These run against a fixture directory with no KiCad installed.

The wx layer gets no unit tests; it is kept thin enough that manual smoke
testing in KiCad is honest coverage. `test_kicad_contract.py` continues to be
the thing that catches KiCad changing underneath us.

## Open items

- **Icons.** Two are needed and neither exists: 64×64 `resources/icon.png` and
  a 24×24 toolbar icon.
- **Ownership of the `com.github.danielboston38` namespace.** The identifier
  embeds the GitHub account. Worth confirming that is the account the repo will
  live under before it is baked into a published identifier, since changing it
  later means a new package rather than an update.

Closed during design: the `kicad_version` floor is 8.0; the package schema is
the v2 schema linked above, checked rather than inferred.

**`plugins/` may contain subdirectories** — settled by downloading a published
package rather than by reading. InteractiveHtmlBom, in the official repository,
ships `plugins/` with five subdirectories including nested Python packages
(`plugins/ecad/kicad_extra/__init__.py`) and asset directories three levels
deep. The documentation's "directly here, no subdirectories" means "do not
nest your plugin inside an extra wrapper folder", not a ban on packages. So
`gate` ships as `plugins/gate/` and needs no flattening.

## Success

A KiCad user installs prefab-gate from the PCM, opens a board, clicks one
button, and gets the same verdict the CLI would give — without their files
being touched, and without having to know what `kicad-cli` is.

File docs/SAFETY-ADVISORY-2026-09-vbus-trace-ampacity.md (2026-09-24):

# Safety Advisory — VBUS input trace is undersized for its own fuse

**Advisory date:** 2026-09-09
**Severity:** Low probability, high consequence. A second fault must occur first.
**Status:** Fixed in source. Existing boards are affected and can be reworked.
**Fixed by:** commit `247334c` — *fix(pcb): reroute /raw_5v out of the 0.2 mm bottleneck past USB-C1* (2026-09-08)

---

## Am I affected?

**Yes, if your board came from either PCBWay fab package:**

| Fab package | 0.2 mm trunk on `/raw_5v` | Affected |
|---|---|---|
| `2026-07-07-13-47-14` | 9.06 mm | **Yes** |
| `2026-07-16-23-35-56` | 9.06 mm | **Yes** |
| Anything built from repo source before `247334c` (2026-09-08) | 7.95–9.06 mm | **Yes** |
| Repo source at or after `247334c` | 0 mm on the trunk | No |

This covers **every board ever fabricated for this project**, including
all boards silkscreened *Kirby's New Dream*. The check walked the copper connectivity
in the shipped Gerber files, not the KiCad source.

Note that the as-fabbed run (9.06 mm) is worse than the repository source immediately
before the fix (7.95 mm), so figures quoted from the repository history understate
what is on a physical board.

**Quick physical check.** Look at the front-copper run between the VBUS pads of the
USB-C connector and pin 2 of F1 (the polyfuse).

- An affected board has a hairline trace about 9 mm long, as thin as a signal trace.
- A corrected board has a wide trace that matches the other power traces.

---

## What is wrong

The VBUS input runs from the USB-C receptacle to F1 through **9.06 mm of 0.2 mm-wide
trace on 1 oz copper**. This segment is the trunk: both VBUS pins (A9 and B9) feed
through it, so **100 % of the board's input current crosses it with no parallel
path.**

The problem is not the trace on its own. It's the trace *relative to the fuse behind
it*. F1, a Littelfuse RHEF200, is guaranteed never to trip below **2.0 A** and only
guaranteed to trip above **3.8 A**.

Electrothermal simulation of the as-fabbed geometry:

| Input current | Peak trace temperature | F1 behavior |
|---|---|---|
| 1.18 A — normal maximum, set by U1's current limit | 48 °C | fine |
| **2.00 A — max current F1 will hold indefinitely** | **105 °C** | **never trips** |
| 2.50 A | 174 °C | may not trip |
| 3.00 A — max from a compliant USB-C source | 303 °C | may not trip |
| 3.80 A — F1's guaranteed trip current | thermal runaway | trips at last |

Damage thresholds for the as-fabbed trace:

- **2.22 A** — exceeds FR4's glass transition (130 °C)
- **2.83 A** — charring and delamination (250 °C)
- F1 is not guaranteed to trip until **3.8 A**

**That leaves a window from about 2.2 A to 3.8 A** where the trace burns and the fuse
isn't guaranteed to do anything at all. The board presents 5.1 kΩ Rd on both CC pins,
so a compliant USB-C source will supply up to 3.0 A, right in the middle of that
window. At 3.0 A the trace passes FR4's glass transition in **0.63 s**, then keeps
heating toward 303 °C while F1 stays below its trip current, possibly forever.

At higher fault currents the trace becomes the fuse. At 10 A the trace reaches the
melting point of copper in **48 ms**. F1 is *specified* to trip within 4.3 s at that
current, so the trace fails about 90 times faster than the part meant to protect it.

The design invariant that was violated is simple:

> The current that damages the narrowest trace must be **higher** than the fuse's trip current.

As fabbed: 2.22 A < 3.8 A ❌  After the fix: 5.64 A > 3.8 A ✅

---

## Root cause: a netclass pattern that never matched

The trace was not routed carelessly. It was routed **exactly as the board's own rules
instructed** — the rules were just wrong.

The board defines two netclasses: `Default` at 0.2 mm track width, and `Power` at
0.8 mm. Nets are assigned to `Power` by name pattern. At fab time those patterns were:

```
Power  <-  /5V*
Power  <-  GND*
Power  <-  VBUS
```

The USB input net is named **`/raw_5v`**. It matches none of those patterns — not
`/5V*`, and not `VBUS`. So the highest-current net on the entire board silently fell
through to **`Default`, 0.2 mm**, and the router faithfully gave it 0.2 mm. The sibling
net `/fused_5v` fell through the same gap.

`/raw_5v` was only added to the `Power` pattern list on 2026-09-07, one day before the
reroute. So the fix had two halves: correcting the netclass assignment, and then
**manually rerouting the trace to the 0.8 mm it should have been all along.**

### Why DRC never caught it

Because it is not a DRC violation. KiCad's design-rule checker enforces the *board-wide*
`min_track_width`, which is set to **0.2 mm** here. It does **not** enforce a netclass's
`track_width`, which is a default for newly routed tracks rather than a constraint.

A 0.2 mm trace on a net whose netclass specifies 0.8 mm is therefore completely legal.
**The affected boards passed DRC with zero errors**, and passed ERC, and passed
`check_nets.py`, which verifies net assignment rather than geometry. Every automated
gate this project had was blind to it in a different way.

This is the general lesson worth taking away from the advisory: **a netclass is only as
good as the pattern that assigns nets to it, and nothing in the standard toolchain will
tell you when a pattern fails to match the net you meant.**

---

## Audit of the other power nets

Because the root cause was a pattern gap rather than a routing mistake, every
current-carrying net was re-checked for the same defect. Results:

| Net | Narrowest copper on its current path | Verdict |
|---|---|---|
| `/raw_5v` (USB-C → F1) | **0.20 mm × 9.06 mm** as fabbed | **The defect. Fixed in `247334c`.** |
| `/fused_5v` (F1 → U1 IN) | 0.60 mm | **OK** — 68 °C at F1's 3.8 A trip; exceeds Tg only at 5.43 A |
| `/5V` (U1 OUT → console) | 0.20 mm | **OK** — see below |
| `GND` | 0.40 mm + pour | OK |

**`/5V` deserves an explanation,** because it also carries 0.2 mm copper and it is the
output rail. It is safe for a specific reason: it sits **downstream of U1's current
limit**, which is hard-capped at 1.26 A worst case by the 22 kΩ on ILIM. A 0.2 mm trace
at 1.26 A settles at about 50 °C. U1 protects it in a way that F1 could never protect
`/raw_5v`.

That contrast is the whole point of this advisory: `/raw_5v` was the **only** high-current
net upstream of the current limit, guarded solely by a fuse whose trip current it could
not survive.

The 0.40 mm copper on `/fused_5v` goes to U1 pin 3 (EN) and C3, not to pin 1 (IN). EN is
a high-impedance input drawing ±0.5 µA, so that branch carries no meaningful current.

---

## How dangerous is this in practice?

**Be reassured about normal use.** Under normal operation the trace runs at 48 °C and
costs 17 mV of rail sag. It is not marginal, it is not degrading, and it will not fail
on its own. A board that works today will keep working. This is a *fault-tolerance*
defect, not a wear-out or reliability defect — which is exactly why it survived bench
testing and shipped.

**The risk requires a second fault first.** Something downstream of the trace but
upstream of U1's current limit has to fail short. Realistic candidates:

- **C3 (100 nF MLCC) cracking short** — the classic ceramic-capacitor failure from
  board flex, and this board gets installed inside a console with cables pulling on it.
- **U1 input failure** — already a known unprotected path: D1 does not clamp below
  U1's 7 V absolute maximum (see *Known Issues*), so a surge can take U1 out.
- A solder bridge or debris across F1's input or U1's input pins.

If that happens, instead of the fuse cleanly interrupting, you get a trace heating
past 300 °C inside a closed plastic shell, with the fuse possibly never tripping.
Nearest neighboring copper is 0.43 mm (GND) and 0.69 mm (CC2), so sustained charring
could also leave a conductive carbon path toward the CC lines.

Probability is low. Consequence is a hot spot inside a sealed console. That combination
is why this is being published rather than quietly fixed.

---

## What you should do

Pick one of these four options.

### Option 1 — Bodge wire (recommended, about 15 minutes)

A bodge wire is a wire soldered across a finished board to make a new connection.
This one runs in parallel with the hairline trace and carries the current in its
place.

1. Use insulated wire, **24 AWG or thicker**.
2. Solder one end to **F1 pin 2**. This pin is through-hole and easy to solder.
3. Solder the other end to the **VBUS copper of the USB-C connector**.

For step 3, either solder to the connector's VBUS pin, or scrape a window in the
soldermask on the wide 0.8 mm section next to the connector and tin it.

24 AWG has a cross-section of 0.205 mm² against the trace's 0.007 mm², about 29 times
as much, so the original trace stops mattering entirely. This restores the correct order: the fuse becomes the weakest
element again, which is the whole point of fitting one.

### Option 2 — Reinforce the existing trace (about 10 minutes, partial)

1. Scrape the soldermask off the 9 mm run.
2. Flood the exposed copper with solder.

This helps, but less than it looks. Solder has about 8 times the resistivity of
copper, so even a generous bead adds only about 50 % to the effective conductance.
It's better than nothing, but not as good as a wire.

### Option 3 — Accept the risk, with awareness

If the board runs from a modest supply and you're comfortable with the risk, follow
these precautions:

- Don't leave the board powered unattended.
- If the USB end of the board gets warm to the touch, unplug it immediately.
- If you smell hot resin, unplug it immediately.

Normal operation is genuinely fine. You are only exposed if something else fails first.

### Option 4 — Rebuild from corrected source

Build a new board from `247334c` or later.

Current `main` also carries unrelated v2 changes (new Switchcraft jack footprints),
so it isn't a drop-in replacement for a v1 bench board.

### What *not* to do

> [!CAUTION]
> **Do not fit a lower-rated fuse to close the gap.**
> To protect a 2.22 A trace, the PPTC would have to trip below that current, which
> means a hold current below about 1.1 A. That's under the board's own 1.18 A operating
> limit, so the fuse would trip in normal use. Fix the trace, not the fuse.

---

## How this was found and verified

Found incidentally during unrelated bench testing, then characterized by simulation
after the fix, to establish what a board carrying the fault would actually do.

**Method.** A distributed electrothermal model of the route: discretized into 0.25 mm
slices, each with temperature-dependent copper resistance, vertical heat loss through
the FR4, and lateral thermal conduction between slices. Solved in ngspice.

**Validation.** The model reproduces IPC-2221 external-layer ampacity within ±8 % from
0.5–2 A, exact at its calibration point. An independent Onderdonk adiabatic fusing
calculation agrees with the simulated 10 A fusing time to about 8 %.

**Geometry.** Taken by walking copper connectivity in the shipped Gerber files for both
fab packages — the boards as actually manufactured, not the KiCad source.

**Conservatism.** The IPC-2221 calibration takes no credit for the B.Cu ground pour
1.51 mm below the trace, so the temperatures above are pessimistic. A sensitivity sweep
was run scaling thermal resistance down to credit that plane:

| Thermal resistance | Exceeds FR4 Tg | Chars |
|---|---|---|
| calibrated (no plane credit) | 2.22 A | 2.83 A |
| 80 % | 2.44 A | 3.12 A |
| 65 % | 2.67 A | 3.41 A |
| 50 % | 2.93 A | 3.75 A |
| 40 % (very generous) | 2.95 A | 3.76 A |

Even crediting the plane with a 60 % reduction in thermal resistance, the charring
threshold asymptotes at **3.76 A — still below F1's 3.8 A guaranteed trip current**.
**Under every assumption tested, the trace is damaged before the fuse is guaranteed to
act.**

**Limits.** Above roughly 300 °C the model is qualitative only — FR4 decomposes and the
thermal parameters stop being valid. Treat runaway figures as "destructive", not as
temperatures. The carbon-tracking secondary effect is reasoned from clearance geometry,
not simulated, and is the least certain claim here.

---

## Reproducing this yourself

The full simulation harness is published in
[`sim/vbus-trace-ampacity/`](../sim/vbus-trace-ampacity/):

```bash
brew install ngspice        # or: apt install ngspice
python3 sim/vbus-trace-ampacity/run_all.py
```

It regenerates every number quoted above, including the validation checks and the
sensitivity sweep. The harness README documents the model, its provenance, and — more
usefully — a list of the assumptions most worth attacking if you want to falsify this.

Independent review is welcome and actively wanted. Please open an issue if any of it
does not hold up.

---

## Credits

Reported and fixed by the project author. Analysis performed with Claude (Anthropic);
see the Disclosure section of the README. Independently verify before relying on any
of it — including this advisory.

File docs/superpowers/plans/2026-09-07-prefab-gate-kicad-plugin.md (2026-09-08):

# prefab-gate KiCad Plugin Implementation Plan

> **For agentic workers:** REQUIRED SUB-SKILL: Use superpowers:subagent-driven-development (recommended) or superpowers:executing-plans to implement this plan task-by-task. Steps use checkbox (`- [ ]`) syntax for tracking.

**Goal:** Ship prefab-gate as a KiCad Plugin and Content Manager package, so a KiCad user can run the gate from a toolbar button without a command line.

**Architecture:** A thin wx `ActionPlugin` calls the existing gate through its own `--json` contract. Two pure-Python helpers do the work worth testing — `staging` assembles a minimal project copy in a temp directory, `runner` invokes the gate in-process and returns a structured result. The wx layer only renders. No gate logic is reimplemented.

**Tech Stack:** Python 3 (stdlib only), `pcbnew` + `wx` (supplied by KiCad, never imported by the tested modules), `unittest`.

**Spec:** `docs/superpowers/specs/2026-09-07-prefab-gate-kicad-plugin-design.md`

## Global Constraints

- **Stdlib only.** KiCad's bundled Python cannot `pip install`. No third-party imports anywhere in shipped code.
- **The plugin changes nothing without explicitly asking.** It never writes to the user's project. Check only; no packaging from the GUI.
- **Never run against the open board.** DRC uses `--refill-zones --save-board` and would rewrite the file under the editor. Always stage a copy.
- **The staged copy is a whitelist:** `<name>.kicad_pcb`, every `*.kicad_sch`, `<name>.kicad_pro`, `<name>.kicad_dru`, `fp-lib-table`, `sym-lib-table`, and any `${KIPRJMOD}`-relative library those tables name. Never the whole directory. The library tables were added after measurement — without them the staged run invented two `lib_footprint_issues` findings.
- **Basenames must be preserved when staging.** `kicad-cli pcb drc` derives the schematic from the board's basename and has no flag to override it.
- **One implementation of the policy.** Blocking-vs-cosmetic decisions live in `gate/`; the plugin consumes them.
- **Tests are stdlib `unittest`, no pytest.** Run with:
  `cd prefab-gate/scripts && PYTHONPATH=. python3 -m unittest discover -s ../tests -p 'test_*.py'`
- **Tested modules must import without `pcbnew` or `wx` present.**
- PCM manifest values, verbatim: `identifier` `com.github.danielboston38.prefab-gate`, `type` `plugin`, `license` `MIT`, `kicad_version` `8.0`, `status` `testing`.
- PCM `version` must match `^\d{1,4}(\.\d{1,4}(\.\d{1,6})?)?$` — **no pre-release suffixes**.
- `download_sha256` / `download_url` / `download_size` / `install_size` **must be absent** from the `metadata.json` inside the archive.

---

## File Structure

| File | Responsibility |
|---|---|
| `prefab-gate/kicad/plugin/__init__.py` | Register the action with pcbnew; stay importable without it |
| `prefab-gate/kicad/plugin/staging.py` | Decide which files a project needs; copy them. No KiCad imports |
| `prefab-gate/kicad/plugin/runner.py` | Invoke the gate, return `(code, verdict, messages, zones_were_stale)`. No KiCad imports |
| `prefab-gate/kicad/plugin/action.py` | wx dialog. Rendering only |
| `prefab-gate/kicad/plugin/icon24.png` | Toolbar icon, 24×24 |
| `prefab-gate/kicad/icon.png` | PCM listing icon, 64×64 |
| `prefab-gate/kicad/metadata.json` | PCM manifest |
| `prefab-gate/kicad/build_pcm.py` | Build the archive; emit submission metadata |
| `prefab-gate/tests/test_staging.py` | Tests for staging |
| `prefab-gate/tests/test_runner.py` | Tests for runner |
| `prefab-gate/tests/test_build_pcm.py` | Tests for the archive layout |

**Deliberate deviation from the spec, flagged for review.** The spec says `staging.collect()` refuses when no schematic sits beside the board. This plan does **not** implement that. The gate already treats a missing schematic as a blocking `parity_not_run` finding, with a better message than staging could give, and duplicating that check would be a second implementation of the same policy — which the spec elsewhere forbids. Staging refuses only when there is no board file at all, which is a precondition for doing anything rather than a policy call.

---

### Task 1: Staging — decide and copy

**Files:**
- Create: `prefab-gate/kicad/plugin/staging.py`
- Test: `prefab-gate/tests/test_staging.py`

**Interfaces:**
- Consumes: nothing.
- Produces: `StagingError(Exception)`; `collect(board_path: str) -> list[str]` (absolute paths, board first); `stage(board_path: str, dest: str) -> str` (returns staged board path).

- [x] **Step 1: Write the failing tests**

```python
"""Staging picks the files DRC needs and nothing else."""
import os
import sys
import tempfile
import unittest

sys.path.insert(0, os.path.join(os.path.dirname(os.path.abspath(__file__)),
                                "..", "kicad"))

from plugin import staging  # noqa: E402

def _project(tmp, *, pro=True, dru=True, sheets=()):
    """A believable KiCad project directory. Returns the board path."""
    board = os.path.join(tmp, "demo.kicad_pcb")
    open(board, "w").write("(kicad_pcb)")
    open(os.path.join(tmp, "demo.kicad_sch"), "w").write("(kicad_sch)")
    for name in sheets:
        open(os.path.join(tmp, name + ".kicad_sch"), "w").write("(kicad_sch)")
    if pro:
        open(os.path.join(tmp, "demo.kicad_pro"), "w").write("{}")
    if dru:
        open(os.path.join(tmp, "demo.kicad_dru"), "w").write("(version 1)")
    return board

class CollectTest(unittest.TestCase):

    def test_board_comes_first(self):
        with tempfile.TemporaryDirectory() as tmp:
            board = _project(tmp)
            self.assertEqual(staging.collect(board)[0], os.path.abspath(board))

    def test_collects_every_schematic_sheet(self):
        """Hierarchical designs have more than the root sheet, and parity
        needs all of them."""
        with tempfile.TemporaryDirectory() as tmp:
            board = _project(tmp, sheets=("power", "video"))
            names = {os.path.basename(p) for p in staging.collect(board)}
            self.assertEqual(
                {"demo.kicad_sch", "power.kicad_sch", "video.kicad_sch"},
                {n for n in names if n.endswith(".kicad_sch")})

    def test_collects_project_and_rules_files(self):
        """Severities live in .kicad_pro and custom rules in .kicad_dru.
        Without them DRC silently uses defaults and judges a different board."""
        with tempfile.TemporaryDirectory() as tmp:
            board = _project(tmp)
            names = {os.path.basename(p) for p in staging.collect(board)}
            self.assertIn("demo.kicad_pro", names)
            self.assertIn("demo.kicad_dru", names)

    def test_tolerates_missing_optional_sidecars(self):
        with tempfile.TemporaryDirectory() as tmp:
            board = _project(tmp, pro=False, dru=False)
            names = {os.path.basename(p) for p in staging.collect(board)}
            self.assertEqual({"demo.kicad_pcb", "demo.kicad_sch"}, names)

    def test_excludes_everything_drc_does_not_read(self):
        """3D models and libraries are what make projects large; footprints
        are embedded in the board and symbols in the schematic."""
        with tempfile.TemporaryDirectory() as tmp:
            board = _project(tmp)
            os.mkdir(os.path.join(tmp, "lib.pretty"))
            open(os.path.join(tmp, "lib.pretty", "a.kicad_mod"), "w").write("x")
            open(os.path.join(tmp, "part.step"), "w").write("x" * 1000)
            open(os.path.join(tmp, "board-F_Cu.gbr"), "w").write("x")
            open(os.path.join(tmp, "backup.zip"), "w").write("x")
            names = {os.path.basename(p) for p in staging.collect(board)}
            for unwanted in ("a.kicad_mod", "part.step", "board-F_Cu.gbr",
                             "backup.zip"):
                self.assertNotIn(unwanted, names)

    def test_unsaved_board_refuses(self):
        """pcbnew returns an empty filename for a board never saved."""
        with self.assertRaises(staging.StagingError):
            staging.collect("")

    def test_missing_board_refuses(self):
        with self.assertRaises(staging.StagingError):
            staging.collect("/nonexistent/demo.kicad_pcb")

class StageTest(unittest.TestCase):

    def test_preserves_basenames(self):
        """kicad-cli derives the schematic from the board's basename."""
        with tempfile.TemporaryDirectory() as tmp, \
             tempfile.TemporaryDirectory() as dest:
            staging.stage(_project(tmp), dest)
            self.assertTrue(os.path.isfile(os.path.join(dest, "demo.kicad_pcb")))
            self.assertTrue(os.path.isfile(os.path.join(dest, "demo.kicad_sch")))

    def test_returns_the_staged_board(self):
        with tempfile.TemporaryDirectory() as tmp, \
             tempfile.TemporaryDirectory() as dest:
            staged = staging.stage(_project(tmp), dest)
            self.assertEqual(os.path.join(dest, "demo.kicad_pcb"), staged)
            self.assertTrue(os.path.isfile(staged))

    def test_leaves_the_originals_alone(self):
        """The whole reason staging exists."""
        with tempfile.TemporaryDirectory() as tmp, \
             tempfile.TemporaryDirectory() as dest:
            board = _project(tmp)
            before = {n: open(os.path.join(tmp, n)).read()
                      for n in os.listdir(tmp)}
            staging.stage(board, dest)
            after = {n: open(os.path.join(tmp, n)).read()
                     for n in os.listdir(tmp)}
            self.assertEqual(before, after)

if __name__ == "__main__":
    unittest.main()
```

- [x] **Step 2: Run the tests to verify they fail**

Run: `cd prefab-gate/scripts && PYTHONPATH=. python3 -m unittest discover -s ../tests -p 'test_staging.py' -v`
Expected: FAIL — `ModuleNotFoundError: No module named 'plugin'`

- [x] **Step 3: Write the implementation**

```python
"""Assemble the smallest project copy kicad-cli DRC needs.

DRC runs with --refill-zones --save-board, which rewrites the board in place.
Run from a plugin that would be the file open in the editor, so the gate is
pointed at a copy instead. This module decides what goes into that copy.

It is a whitelist, not a directory copy. 3D models and footprint or symbol
libraries are excluded because footprints are embedded in the .kicad_pcb and
symbols in the .kicad_sch — DRC never reads the libraries, and they are what
makes a KiCad project large. A real project measured 0.41 MB staged against a
79 MB directory.

.kicad_pro and .kicad_dru are not optional extras. DRC severities live in the
first and custom rules in the second; a copy without them falls back to
defaults and returns a verdict about a design the user does not have — a
failure that looks exactly like success.
"""
import glob
import os
import shutil

class StagingError(Exception):
    """There is no board file to stage."""

def collect(board_path):
    """Absolute paths of every file DRC needs. The board is always first.

    A missing schematic is deliberately not an error here. The gate treats it
    as a blocking parity_not_run finding with a better explanation than this
    module could give, and duplicating the check would put the same policy in
    two places.
    """
    if not board_path:
        raise StagingError(
            "This board has not been saved yet, so there is no file to check. "
            "Save it and run the gate again.")
    board = os.path.abspath(board_path)
    if not os.path.isfile(board):
        raise StagingError(f"No board file at {board}.")

    project = os.path.dirname(board)
    stem = os.path.splitext(os.path.basename(board))[0]

    files = [board]
    files.extend(sorted(glob.glob(os.path.join(project, "*.kicad_sch"))))
    for extension in (".kicad_pro", ".kicad_dru"):
        sidecar = os.path.join(project, stem + extension)
        if os.path.isfile(sidecar):
            files.append(sidecar)
    return files

def stage(board_path, dest):
    """Copy the collected files into dest; return the staged board's path.

    Basenames are preserved because kicad-cli derives the schematic from the
    board's basename and has no flag to override it.
    """
    files = collect(board_path)
    for source in files:
        shutil.copy2(source, os.path.join(dest, os.path.basename(source)))
    return os.path.join(dest, os.path.basename(files[0]))
```

- [x] **Step 4: Run the tests to verify they pass**

Run: `cd prefab-gate/scripts && PYTHONPATH=. python3 -m unittest discover -s ../tests -p 'test_staging.py' -v`
Expected: PASS, 10 tests

- [x] **Step 5: Run the whole suite to confirm nothing regressed**

Run: `cd prefab-gate/scripts && PYTHONPATH=. python3 -m unittest discover -s ../tests -p 'test_*.py'`
Expected: PASS, 192 tests

- [x] **Step 6: Commit**

```bash
git add prefab-gate/kicad/plugin/staging.py prefab-gate/tests/test_staging.py
git commit -m "feat(kicad-plugin): stage a minimal project copy for DRC

DRC rewrites the board to refill zones, so a plugin must never point it at
the file open in the editor. Staging copies a four-file whitelist to a temp
directory instead: the board, every schematic sheet, and the .kicad_pro and
.kicad_dru that carry severities and custom rules.

The whitelist is the point. 3D models and libraries are excluded because
footprints and symbols are embedded in the board and schematic, and they are
what make projects large — 0.41 MB staged against a 79 MB directory.

Omitting .kicad_pro or .kicad_dru would be the subtle failure: DRC would fall
back to default rules and return a confident verdict about a different design."
```

---

### Task 2: Runner — invoke the gate, detect stale fills

**Files:**
- Create: `prefab-gate/kicad/plugin/runner.py`
- Test: `prefab-gate/tests/test_runner.py`

**Interfaces:**
- Consumes: `staging.stage` (Task 1).
- Produces: `Result` namedtuple with fields `code: int`, `verdict: dict | None`, `messages: str`, `zones_were_stale: bool`; `run_check(board_path, main=None, hasher=None) -> Result`.

Under `--json` the gate writes only the verdict to stdout and every other message to stderr, so parsing stdout as JSON is a supported contract rather than screen-scraping.

Stale zone fills are detected by hashing the staged board before and after, **not** by matching the gate's note. The gate itself refuses to key on message wording, and its note says "should be committed" while naming a temp path — true for the CLI, nonsense in a dialog.

- [x] **Step 1: Write the failing tests**

```python
"""The runner adapts the gate's CLI contract for the GUI."""
import json
import os
import sys
import tempfile
import unittest

sys.path.insert(0, os.path.join(os.path.dirname(os.path.abspath(__file__)),
                                "..", "kicad"))

from plugin import runner  # noqa: E402

PASSING = {"passed": True, "blocking": [], "cosmetic": []}

def _fake_main(stdout="", stderr="", code=0, writes=None):
    """Stand in for prefab_gate.main, which the runner calls in-process."""
    def main(argv):
        if writes is not None:
            open(argv[1], "w").write(writes)
        sys.stdout.write(stdout)
        sys.stderr.write(stderr)
        return code
    return main

class RunCheckTest(unittest.TestCase):

    def setUp(self):
        self.tmp = tempfile.TemporaryDirectory()
        self.board = os.path.join(self.tmp.name, "demo.kicad_pcb")
        open(self.board, "w").write("(kicad_pcb)")
        open(os.path.join(self.tmp.name, "demo.kicad_sch"), "w").write("(x)")
        self.addCleanup(self.tmp.cleanup)

    def test_parses_the_json_verdict_from_stdout(self):
        result = runner.run_check(
            self.board, main=_fake_main(stdout=json.dumps(PASSING)))
        self.assertEqual(PASSING, result.verdict)
        self.assertEqual(0, result.code)

    def test_keeps_stderr_as_messages(self):
        result = runner.run_check(
            self.board,
            main=_fake_main(stdout=json.dumps(PASSING), stderr="kicad-cli missing"))
        self.assertIn("kicad-cli missing", result.messages)

    def test_survives_a_gate_that_printed_no_verdict(self):
        """Exit 3 paths print to stderr and never emit a verdict."""
        result = runner.run_check(
            self.board, main=_fake_main(stderr="boom", code=3))
        self.assertIsNone(result.verdict)
        self.assertEqual(3, result.code)
        self.assertIn("boom", result.messages)

    def test_reports_stale_zone_fills_when_the_board_changed(self):
        result = runner.run_check(
            self.board,
            main=_fake_main(stdout=json.dumps(PASSING), writes="(refilled)"))
        self.assertTrue(result.zones_were_stale)

    def test_no_stale_report_when_the_board_is_untouched(self):
        result = runner.run_check(
            self.board, main=_fake_main(stdout=json.dumps(PASSING)))
        self.assertFalse(result.zones_were_stale)

    def test_runs_against_a_copy_not_the_original(self):
        """The guarantee: the user's board is never the file DRC is given."""
        original = open(self.board).read()
        runner.run_check(
            self.board,
            main=_fake_main(stdout=json.dumps(PASSING), writes="(refilled)"))
        self.assertEqual(original, open(self.board).read())

    def test_checks_a_path_inside_a_temporary_directory(self):
        seen = {}

        def main(argv):
            seen["board"] = argv[1]
            sys.stdout.write(json.dumps(PASSING))
            return 0

        runner.run_check(self.board, main=main)
        self.assertNotEqual(os.path.abspath(self.board),
                            os.path.abspath(seen["board"]))
        self.assertFalse(os.path.exists(seen["board"]),
                         "the staging directory must be cleaned up")

if __name__ == "__main__":
    unittest.main()
```

- [x] **Step 2: Run the tests to verify they fail**

Run: `cd prefab-gate/scripts && PYTHONPATH=. python3 -m unittest discover -s ../tests -p 'test_runner.py' -v`
Expected: FAIL — `ModuleNotFoundError: No module named 'plugin.runner'`

- [x] **Step 3: Write the implementation**

```python
"""Run the gate against a staged copy and return something a dialog can render.

The gate is invoked through prefab_gate.main so that the plugin and the command
line share one implementation of the policy. Under --json the gate puts only
the verdict on stdout and every other message on stderr, which makes parsing
stdout a supported contract rather than screen-scraping.
"""
import collections
import hashlib
import io
import json
import os
import sys
import tempfile
from contextlib import redirect_stderr, redirect_stdout

# Relative: PCM installs this package under a directory of its own choosing, so
# the package name is not "plugin" once installed. An absolute import works in
# the repo and breaks in the field.
from . import staging

Result = collections.namedtuple(
    "Result", "code verdict messages zones_were_stale")

def _sha256(path):
    digest = hashlib.sha256()
    with open(path, "rb") as handle:
        for block in iter(lambda: handle.read(65536), b""):
            digest.update(block)
    return digest.hexdigest()

def _gate_main():
    """Import the gate lazily, so this module imports without it on the path.

    Two layouts have to work. Installed, PCM flattens everything into one
    directory, so prefab_gate.py is a sibling. In the repo it lives at
    ../../scripts. Nearest first, and neither is assumed.
    """
    here = os.path.dirname(os.path.abspath(__file__))
    for candidate in (here,
                      os.path.normpath(os.path.join(here, "..", "..", "scripts"))):
        if os.path.isfile(os.path.join(candidate, "prefab_gate.py")):
            if candidate not in sys.path:
                sys.path.insert(0, candidate)
            break
    import prefab_gate
    return prefab_gate.main

def run_check(board_path, main=None, hasher=None):
    """Stage the project, check the copy, and report what happened.

    Stale zone fills are detected by hashing the staged board either side of
    the run rather than by reading the gate's note. The gate declines to key on
    message wording and so does this; its note also says the file "should be
    committed" while naming a path inside a temporary directory, which is true
    for the CLI and meaningless in a dialog.
    """
    main = main or _gate_main()
    hasher = hasher or _sha256

    with tempfile.TemporaryDirectory(prefix="prefab-gate-") as staged_dir:
        board = staging.stage(board_path, staged_dir)
        before = hasher(board)

        out, err = io.StringIO(), io.StringIO()
        with redirect_stdout(out), redirect_stderr(err):
            code = main(["check", board, "--json"])

        stale = hasher(board) != before

    raw = out.getvalue().strip()
    verdict = None
    if raw:
        try:
            verdict = json.loads(raw)
        except json.JSONDecodeError:
            verdict = None
    return Result(code=code, verdict=verdict,
                  messages=err.getvalue().strip(), zones_were_stale=stale)
```

- [x] **Step 4: Run the tests to verify they pass**

Run: `cd prefab-gate/scripts && PYTHONPATH=. python3 -m unittest discover -s ../tests -p 'test_runner.py' -v`
Expected: PASS, 7 tests

- [x] **Step 5: Run the whole suite**

Run: `cd prefab-gate/scripts && PYTHONPATH=. python3 -m unittest discover -s ../tests -p 'test_*.py'`
Expected: PASS, 199 tests

- [x] **Step 6: Commit**

```bash
git add prefab-gate/kicad/plugin/runner.py prefab-gate/tests/test_runner.py
git commit -m "feat(kicad-plugin): run the gate on a staged copy

Calls prefab_gate.main so the GUI and the CLI share one implementation of the
policy. Under --json the gate emits only the verdict on stdout and everything
else on stderr, so parsing stdout is a contract rather than screen-scraping.

Stale zone fills are detected by hashing the staged board either side of the
run, not by matching the gate's note. The gate refuses to key on message
wording and neither does this — and that note says the board 'should be
committed' while naming a temp path, which is true for the CLI and nonsense in
a dialog."
```

---

### Task 3: The action plugin

**Files:**
- Create: `prefab-gate/kicad/plugin/action.py`
- Create: `prefab-gate/kicad/plugin/__init__.py`

**Interfaces:**
- Consumes: `runner.run_check` and `runner.Result` (Task 2); `staging.StagingError` (Task 1).
- Produces: `PrefabGateAction(pcbnew.ActionPlugin)`; `summarise(result, board_path) -> str`.

`summarise` is deliberately separated from the wx code so the wording can be read and changed without KiCad. The dialog itself is left untested; it is kept thin enough that manual smoke testing is honest coverage.

- [x] **Step 1: Write `action.py`**

```python
"""The toolbar button. Rendering only — no policy lives here."""
import datetime
import os

import wx

import pcbnew

from . import runner, staging

def summarise(result, board_path):
    """The dialog text for a finished run.

    Two things are stated whatever the verdict, because a quiet plugin would
    mislead in both cases. Which file was read: unsaved editor changes cannot
    be detected reliably from a plugin, so rather than guess, the path and its
    modification time are shown and the user resolves the ambiguity. And that
    stale zone fills were reported rather than repaired: the CLI fixes them as
    a side effect of saving, this cannot, and a clean pass on a board whose
    on-disk fills are stale is the exact fault the gate exists to catch.
    """
    stamp = "unknown"
    if os.path.isfile(board_path):
        stamp = datetime.datetime.fromtimestamp(
            os.path.getmtime(board_path)).strftime("%Y-%m-%d %H:%M:%S")
    lines = [f"Checked: {board_path}", f"Last saved: {stamp}", ""]

    if result.verdict is None:
        lines.append("The gate could not run.")
        if result.messages:
            lines += ["", result.messages]
        return "\n".join(lines)

    blocking = result.verdict.get("blocking", [])
    cosmetic = result.verdict.get("cosmetic", [])
    lines.append("PASSED — nothing blocking."
                 if result.verdict.get("passed")
                 else f"BLOCKED — {len(blocking)} blocking finding(s).")

    for finding in blocking:
        lines.append(f"  ✗ {finding.get('type')}: {finding.get('description')}")
    if cosmetic:
        lines.append(f"\n{len(cosmetic)} cosmetic finding(s), waived:")
        for finding in cosmetic:
            lines.append(f"  · {finding.get('type')}: {finding.get('description')}")

    if result.zones_were_stale:
        lines += ["",
                  "Your zone fills are stale. This check refilled them on a "
                  "copy and did not touch your board — refill and save before "
                  "exporting a fab package."]

    lines += ["", "This check wrote nothing. Packaging stays on the command "
                  "line, where the board is not being edited."]
    return "\n".join(lines)

class PrefabGateAction(pcbnew.ActionPlugin):

    def defaults(self):
        self.name = "prefab-gate: check this board"
        self.category = "Design verification"
        self.description = ("Run DRC with zone refill and schematic parity "
                            "against a copy, and report what blocks fab.")
        self.show_toolbar_button = True
        self.icon_file_name = os.path.join(
            os.path.dirname(os.path.abspath(__file__)), "icon24.png")

    def Run(self):
        board_path = pcbnew.GetBoard().GetFileName()
        try:
            result = runner.run_check(board_path)
        except staging.StagingError as exc:
            wx.MessageBox(str(exc), "prefab-gate", wx.OK | wx.ICON_WARNING)
            return

        icon = wx.ICON_INFORMATION
        if result.verdict is None or not result.verdict.get("passed"):
            icon = wx.ICON_WARNING
        dialog = wx.MessageDialog(None, summarise(result, board_path),
                                  "prefab-gate", wx.OK | icon)
        dialog.ShowModal()
        dialog.Destroy()
```

- [x] **Step 2: Write `__init__.py`**

```python
"""Register the action with pcbnew when running inside KiCad.

pcbnew is absent outside KiCad, and the staging and runner modules must stay
importable there so they can be tested. Only the registration is skipped, and
only when pcbnew itself is missing — a broken action.py still raises, rather
than disappearing behind a bare except.
"""
try:
    import pcbnew  # noqa: F401
except ImportError:
    pass
else:
    from .action import PrefabGateAction

    PrefabGateAction().register()
```

- [x] **Step 3: Verify the tested modules still import without KiCad**

Run: `cd prefab-gate/scripts && PYTHONPATH=. python3 -m unittest discover -s ../tests -p 'test_*.py'`
Expected: PASS, 199 tests — proving `__init__.py` does not drag in `pcbnew`

- [x] **Step 4: Commit**

```bash
git add prefab-gate/kicad/plugin/action.py prefab-gate/kicad/plugin/__init__.py
git commit -m "feat(kicad-plugin): add the toolbar action

The dialog states two things whatever the verdict, because staying quiet about
either would mislead. Which file was read, with its mtime: unsaved editor
changes cannot be detected reliably from a plugin, so it shows what it checked
instead of guessing. And that stale zone fills were reported, not repaired —
the CLI fixes them as a side effect of saving, this cannot, and a clean pass on
a board with stale on-disk fills is the fault the gate exists to catch.

Registration is skipped when pcbnew is absent so the tested modules stay
importable outside KiCad, but only for a missing pcbnew — a broken action still
raises rather than vanishing behind a bare except."
```

---

### Task 4: Icons

**Files:**
- Create: `prefab-gate/kicad/icon.png` (64×64)
- Create: `prefab-gate/kicad/plugin/icon24.png` (24×24)

Both are required: 64×64 for the PCM listing, 24×24 for the pcbnew toolbar. Written with stdlib `zlib` + `struct` so no image library is needed.

- [x] **Step 1: Write the generator and produce both files**

```python
# prefab-gate/kicad/make_icons.py
"""Generate the two PNG icons the PCM and the toolbar require.

Stdlib only — KiCad's bundled Python has no Pillow, and adding a build-time
dependency to draw two flat images would be a poor trade. The mark is a shield
outline with a gate bar across it: verification, and a thing that stays shut.
"""
import os
import struct
import zlib

INK = (0x1F, 0x6F, 0x4B)      # green, "passed"
BAR = (0xF5, 0xF5, 0xF5)

def _shield(x, y, size):
    """True inside a rounded shield centred in a size x size field."""
    u, v = (x + 0.5) / size * 2 - 1, (y + 0.5) / size
    half = 0.86 - 0.34 * v * v
    if v < 0.62:
        return abs(u) <= half
    taper = (1 - v) / 0.38
    return abs(u) <= half * (0.35 + 0.65 * taper)

def _pixels(size):
    bar_top, bar_bottom = int(size * 0.46), int(size * 0.58)
    for y in range(size):
        row = bytearray([0])
        for x in range(size):
            if not _shield(x, y, size):
                row += bytes((0, 0, 0, 0))
            elif bar_top <= y < bar_bottom and size * 0.18 < x < size * 0.82:
                row += bytes(BAR) + b"\xff"
            else:
                row += bytes(INK) + b"\xff"
        yield bytes(row)

def _chunk(tag, payload):
    return (struct.pack(">I", len(payload)) + tag + payload
            + struct.pack(">I", zlib.crc32(tag + payload) & 0xFFFFFFFF))

def write_png(path, size):
    header = struct.pack(">IIBBBBB", size, size, 8, 6, 0, 0, 0)
    body = zlib.compress(b"".join(_pixels(size)), 9)
    with open(path, "wb") as handle:
        handle.write(b"\x89PNG\r\n\x1a\n"
                     + _chunk(b"IHDR", header)
                     + _chunk(b"IDAT", body)
                     + _chunk(b"IEND", b""))

if __name__ == "__main__":
    here = os.path.dirname(os.path.abspath(__file__))
    write_png(os.path.join(here, "icon.png"), 64)
    write_png(os.path.join(here, "plugin", "icon24.png"), 24)
    print("wrote icon.png (64) and plugin/icon24.png (24)")
```

- [x] **Step 2: Run it and verify the dimensions**

```bash
cd prefab-gate/kicad && python3 make_icons.py
python3 -c "
import struct
for p, want in (('icon.png', 64), ('plugin/icon24.png', 24)):
    d = open(p, 'rb').read()
    w, h = struct.unpack('>II', d[16:24])
    print(f'  {p}: {w}x{h}', 'OK' if (w, h) == (want, want) else 'WRONG')
"
```
Expected: `icon.png: 64x64 OK` and `plugin/icon24.png: 24x24 OK`

- [x] **Step 3: Commit**

```bash
git add prefab-gate/kicad/make_icons.py prefab-gate/kicad/icon.png prefab-gate/kicad/plugin/icon24.png
git commit -m "feat(kicad-plugin): add the PCM and toolbar icons

Two are required and they are different sizes: 64x64 for the manager's listing
and 24x24 for the pcbnew toolbar button. Generated from stdlib zlib and struct
rather than committing opaque binaries with no source, and without adding an
image library KiCad's bundled Python cannot install."
```

---

### Task 5: PCM manifest and archive builder

**Files:**
- Create: `prefab-gate/kicad/metadata.json`
- Create: `prefab-gate/kicad/build_pcm.py`
- Test: `prefab-gate/tests/test_build_pcm.py`

**Interfaces:**
- Consumes: everything from Tasks 1–4.
- Produces: `build(repo_root, out_dir) -> (archive_path, submission_metadata_dict)`.

- [x] **Step 1: Write `metadata.json`**

`download_*` fields are deliberately absent — the spec forbids them inside the archive; `build_pcm.py` adds them to the submission copy only.

```json
{
    "$schema": "https://go.kicad.org/pcm/schemas/v1",
    "name": "prefab-gate",
    "description": "Refuses to produce a fab package from a board that has not passed verification.",
    "description_full": "prefab-gate runs kicad-cli DRC with zone refill and schematic parity checking, classifies every finding as blocking or cosmetic, and reports whether the board is fit to fabricate.\n\nThe toolbar button checks and reports. It never writes to your project: the check runs against a copy of the board, schematic, project and custom-rules files in a temporary directory, because DRC refills zones and would otherwise rewrite the board open in your editor.\n\nStale zone fills are reported rather than silently repaired, and the dialog always names the file it read, because unsaved editor changes cannot be detected reliably from a plugin.\n\nExporting a verified fab package - gerbers, drill, CPL and BOM, with a manifest pinning them to the board that was checked - is available from the command line version.",
    "identifier": "com.github.danielboston38.prefab-gate",
    "type": "plugin",
    "author": {
        "name": "Mark Dymek",
        "contact": {
            "web": "https://github.com/danielboston38"
        }
    },
    "license": "MIT",
    "resources": {
        "homepage": "https://github.com/danielboston38/prefab-gate"
    },
    "tags": ["drc", "fabrication", "verification", "gerber", "design-review"],
    "versions": [
        {
            "version": "0.1.0",
            "status": "testing",
            "kicad_version": "8.0"
        }
    ]
}
```

- [x] **Step 2: Write the failing tests**

```python
"""The archive must match KiCad's PCM layout exactly."""
import json
import os
import re
import sys
import tempfile
import unittest
import zipfile

sys.path.insert(0, os.path.join(os.path.dirname(os.path.abspath(__file__)),
                                "..", "kicad"))

import build_pcm  # noqa: E402

REPO = os.path.normpath(os.path.join(os.path.dirname(os.path.abspath(__file__)),
                                     ".."))

class BuildTest(unittest.TestCase):

    def setUp(self):
        self.out = tempfile.TemporaryDirectory()
        self.addCleanup(self.out.cleanup)
        self.archive, self.submission = build_pcm.build(REPO, self.out.name)
        self.names = set(zipfile.ZipFile(self.archive).namelist())

    def test_metadata_sits_at_the_archive_root(self):
        self.assertIn("metadata.json", self.names)

    def test_plugin_code_is_under_plugins(self):
        for expected in ("plugins/__init__.py", "plugins/action.py",
                         "plugins/staging.py", "plugins/runner.py"):
            self.assertIn(expected, self.names)

    def test_the_gate_package_travels_with_the_plugin(self):
        """The plugin imports gate/ — shipping without it installs a plugin
        that cannot run."""
        self.assertTrue(any(n.startswith("plugins/gate/") for n in self.names))
        self.assertIn("plugins/prefab_gate.py", self.names)

    def test_both_icons_are_present(self):
        self.assertIn("resources/icon.png", self.names)
        self.assertIn("plugins/icon24.png", self.names)

    def test_archive_metadata_omits_download_fields(self):
        """The spec forbids them inside the package."""
        packed = json.loads(
            zipfile.ZipFile(self.archive).read("metadata.json"))
        for banned in ("download_sha256", "download_url", "download_size",
                       "install_size"):
            self.assertNotIn(banned, packed["versions"][0])

    def test_submission_metadata_carries_the_download_fields(self):
        version = self.submission["versions"][0]
        self.assertEqual(64, len(version["download_sha256"]))
        self.assertGreater(version["download_size"], 0)
        self.assertGreater(version["install_size"], 0)

    def test_version_has_no_prerelease_suffix(self):
        """The v2 schema rejects them; intent belongs in status."""
        version = self.submission["versions"][0]["version"]
        self.assertRegex(version, r"^\d{1,4}(\.\d{1,4}(\.\d{1,6})?)?$")

    def test_identifier_matches_the_schema(self):
        self.assertRegex(self.submission["identifier"],
                         r"^[a-zA-Z][-a-zA-Z0-9.]{0,98}[a-zA-Z0-9]$")

    def test_no_pycache_is_shipped(self):
        self.assertFalse([n for n in self.names if "__pycache__" in n])

if __name__ == "__main__":
    unittest.main()
```

- [x] **Step 3: Run the tests to verify they fail**

Run: `cd prefab-gate/scripts && PYTHONPATH=. python3 -m unittest discover -s ../tests -p 'test_build_pcm.py' -v`
Expected: FAIL — `ModuleNotFoundError: No module named 'build_pcm'`

- [x] **Step 4: Write `build_pcm.py`**

```python
"""Build the PCM archive and the metadata that describes it.

KiCad expects metadata.json at the archive root, plugin code under plugins/,
and a 64x64 resources/icon.png. The gate package travels inside plugins/ so the
installed plugin can import it.

The download_* fields are computed here rather than maintained by hand, because
three numbers describing an artifact will drift from it otherwise. They are
written only into the submission copy: the spec forbids them inside the
archive.
"""
import hashlib
import json
import os
import zipfile

def _files(root):
    for base, dirs, names in os.walk(root):
        dirs[:] = [d for d in dirs if d != "__pycache__"]
        for name in names:
            if name.endswith(".pyc"):
                continue
            yield os.path.join(base, name)

def build(repo_root, out_dir):
    """Write the archive into out_dir; return (path, submission_metadata)."""
    kicad = os.path.join(repo_root, "kicad")
    metadata = json.load(open(os.path.join(kicad, "metadata.json")))
    version = metadata["versions"][0]["version"]
    archive = os.path.join(out_dir, f"prefab-gate-{version}-pcm.zip")

    install_size = 0
    with zipfile.ZipFile(archive, "w", zipfile.ZIP_DEFLATED) as zf:
        zf.writestr("metadata.json", json.dumps(metadata, indent=4))

        for path in _files(os.path.join(kicad, "plugin")):
            arc = "plugins/" + os.path.relpath(path, os.path.join(kicad, "plugin"))
            zf.write(path, arc)
            install_size += os.path.getsize(path)

        scripts = os.path.join(repo_root, "scripts")
        for path in _files(scripts):
            arc = "plugins/" + os.path.relpath(path, scripts)
            zf.write(path, arc)
            install_size += os.path.getsize(path)

        icon = os.path.join(kicad, "icon.png")
        zf.write(icon, "resources/icon.png")
        install_size += os.path.getsize(icon)

    submission = json.loads(json.dumps(metadata))
    submission["versions"][0].update({
        "download_sha256": hashlib.sha256(open(archive, "rb").read()).hexdigest(),
        "download_size": os.path.getsize(archive),
        "install_size": install_size,
    })
    return archive, submission

if __name__ == "__main__":
    root = os.path.normpath(
        os.path.join(os.path.dirname(os.path.abspath(__file__)), ".."))
    out = os.path.join(root, "dist")
    os.makedirs(out, exist_ok=True)
    path, meta = build(root, out)
    with open(os.path.join(out, "metadata.submission.json"), "w") as handle:
        json.dump(meta, handle, indent=4)
    print(f"archive: {path}")
    print("submission metadata: "
          f"{os.path.join(out, 'metadata.submission.json')}")
    print("Set download_url to the release asset URL before submitting.")
```

- [x] **Step 5: Run the tests to verify they pass**

Run: `cd prefab-gate/scripts && PYTHONPATH=. python3 -m unittest discover -s ../tests -p 'test_build_pcm.py' -v`
Expected: PASS, 9 tests

- [x] **Step 6: Build the archive and check its size**

```bash
cd prefab-gate/kicad && python3 build_pcm.py && ls -lh ../dist/
```
Expected: an archive well under 1 MB — the whole point of not shipping the hardware repo

- [x] **Step 7: Run the whole suite**

Run: `cd prefab-gate/scripts && PYTHONPATH=. python3 -m unittest discover -s ../tests -p 'test_*.py'`
Expected: PASS, 208 tests

- [x] **Step 8: Add `dist/` to the ignore list and commit**

```bash
echo "dist/" >> prefab-gate/.gitignore
git add prefab-gate/kicad/metadata.json prefab-gate/kicad/build_pcm.py \
        prefab-gate/tests/test_build_pcm.py prefab-gate/.gitignore
git commit -m "feat(kicad-plugin): build the PCM archive

Assembles KiCad's expected layout - metadata.json at the root, plugin code and
the gate package under plugins/, a 64x64 resources/icon.png - and computes
download_sha256, download_size and install_size rather than leaving three
numbers to be kept in step with the artifact they describe by hand.

Those fields go only into the submission copy. The spec forbids them inside the
archive, which is an easy rule to break by copying one file to both places, so
a test asserts their absence."
```

---

### Task 6: Manual verification in KiCad

This is the only coverage the wx layer gets, so it is a task rather than a footnote.

- [x] **Step 1: Install the archive**

KiCad → Plugin and Content Manager → *Install from File* → `prefab-gate/dist/prefab-gate-0.1.0-pcm.zip`

- [x] **Step 2: Confirm the gate package survived the install**

Check that `plugins/gate/` is present in the installed plugin directory and was not flattened.

This is expected to pass and is no longer a design risk: the official repository's InteractiveHtmlBom ships `plugins/` with five subdirectories, including nested packages (`plugins/ecad/kicad_extra/__init__.py`) and assets three levels deep. The documentation's "no subdirectories" means "do not wrap your plugin in an extra folder". Verify anyway — it costs one `ls`.

- [x] **Step 3: Run it against the NES board**

Open `nes_power_video.kicad_pcb`, click the toolbar button. Expected: PASSED, 0 blocking, 6 cosmetic silkscreen findings on J2/J3, and the dialog naming the board path and its last-saved time.

- [x] **Step 4: Confirm it wrote nothing**

```bash
cd ~/nes_power_video && git status --short
```
Expected: no modification to `nes_power_video.kicad_pcb`. **This is the plugin's central promise; if the board is dirty, stop.**

- [x] **Step 5: Check the unsaved-board path**

File → New Board, click the button without saving. Expected: the "This board has not been saved yet" message, not a traceback.

- [x] **Step 6: Record the result**

```bash
git commit --allow-empty -m "test(kicad-plugin): verified against KiCad 10.0.6

Installed from file, ran against nes_power_video.kicad_pcb: PASSED, 0
blocking, 6 cosmetic. Board unmodified afterwards, which is the plugin's
central promise. Unsaved-board path reports rather than raising.

Confirms plugins/ tolerates the gate package as a subdirectory, which the
documentation's 'no subdirectories' wording left ambiguous."
```

---

### Task 7: Split into its own repository — **STOP, needs the user**

Everything above is local and reversible. This task creates a public repository and is not.

- [x] **Step 1: Ask before doing anything**

Confirm with the user: the repository name (`prefab-gate`), and **public or private**. Do not create it on assumption.

- [x] **Step 2: Split the history**

```bash
cd ~/nes_power_video
git subtree split --prefix=prefab-gate -b prefab-gate-export
git log --oneline prefab-gate-export | wc -l   # sanity: many commits, not one
```

- [x] **Step 3: Create and push**

```bash
gh repo create prefab-gate --<public|private> \
  --description "Refuses to produce a KiCad fab package from a board that has not passed verification."
git push git@github.com:danielboston38/prefab-gate.git prefab-gate-export:main
```

- [x] **Step 4: Verify the tests pass from a clean clone**

```bash
cd $(mktemp -d) && git clone git@github.com:danielboston38/prefab-gate.git && cd prefab-gate/scripts
PYTHONPATH=. python3 -m unittest discover -s ../tests -p 'test_*.py'
```
Expected: PASS, 208 tests. A green suite in a fresh clone is what proves the split is complete.

- [x] **Step 5: Update the board repo**

Remove `prefab-gate/`, point `.claude-plugin/marketplace.json` at the new repo, and rewrite the README's `python3 prefab-gate/scripts/prefab_gate.py` invocations to use `prefab_gate` on PATH. Commit.

---

### Task 8: Submit to the PCM repository — **STOP, needs the user**

> **Confirm with Mark before submitting.** The address is
> `https://gitlab.com/kicad/addons/metadata` — a merge request adding a
> directory under `packages/` named for the package identifier. The restriction
> that caused earlier confusion is narrow: **do not submit to
> `https://gitlab.com/kicad/addons/repository`**, which is the generated
> repository, not the metadata source. An addon submission is public and
> effectively unsendable, so it is still a stop-and-ask, not an assumption.

- [ ] **Step 1: Publish a release**

Tag `0.1.0` in the new repo and attach `prefab-gate-0.1.0-pcm.zip` as a release asset. Take its download URL.

- [ ] **Step 2: Regenerate the submission metadata**

```bash
cd prefab-gate/kicad && python3 build_pcm.py
```
Set `download_url` in `dist/metadata.submission.json` to the release asset URL. The sha256 must match the asset actually uploaded.

- [ ] **Step 3: Open the merge request, after confirming with Mark**

Fork `https://gitlab.com/kicad/addons/metadata`, create
`packages/com.github.danielboston38.prefab-gate/` containing the submission
`metadata.json` and the 64×64 icon, and open the MR.

**Not** `https://gitlab.com/kicad/addons/repository` — that is the generated
repository and is not where packages are submitted. Several packages sharing a
namespace may go in one MR; this is a single package.

- [ ] **Step 4: Note the ongoing commitment**

KiCad may remove packages with unresolved bugs after 90 days. Record that this is now maintained software with an external audience.

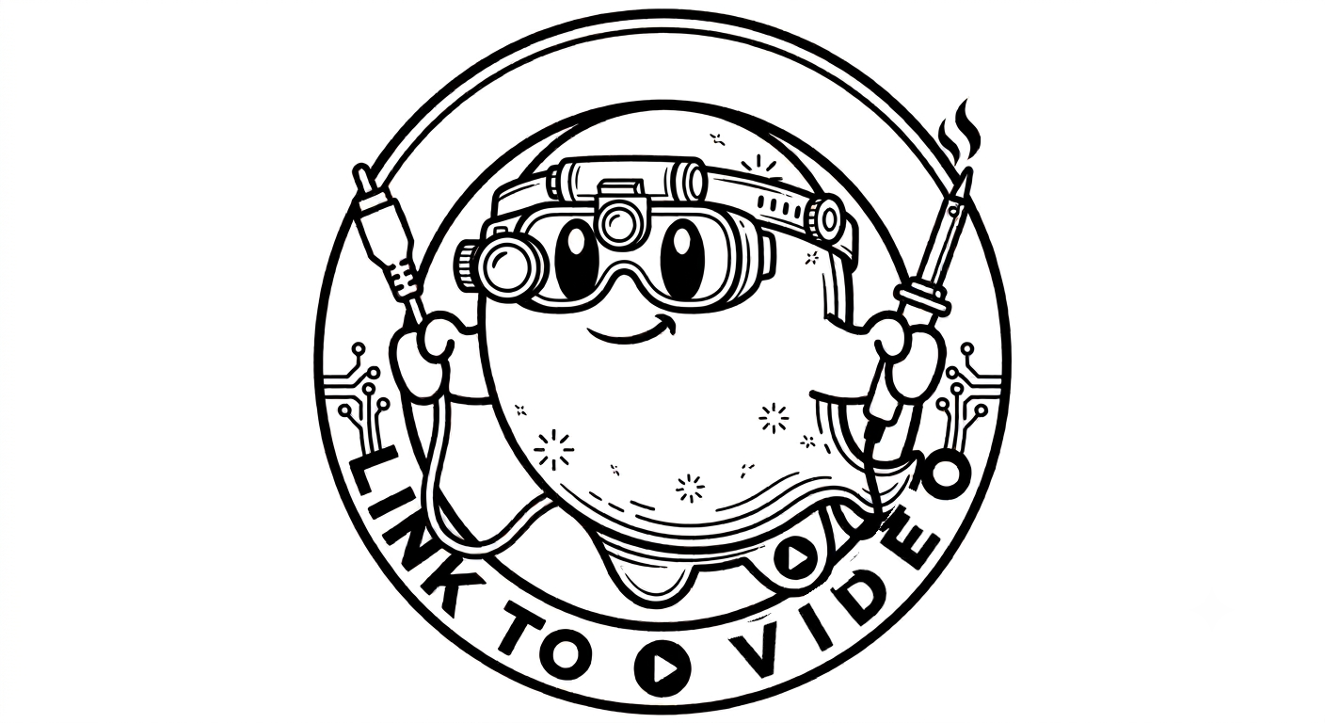
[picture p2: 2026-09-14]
mascot_link_to_video.png

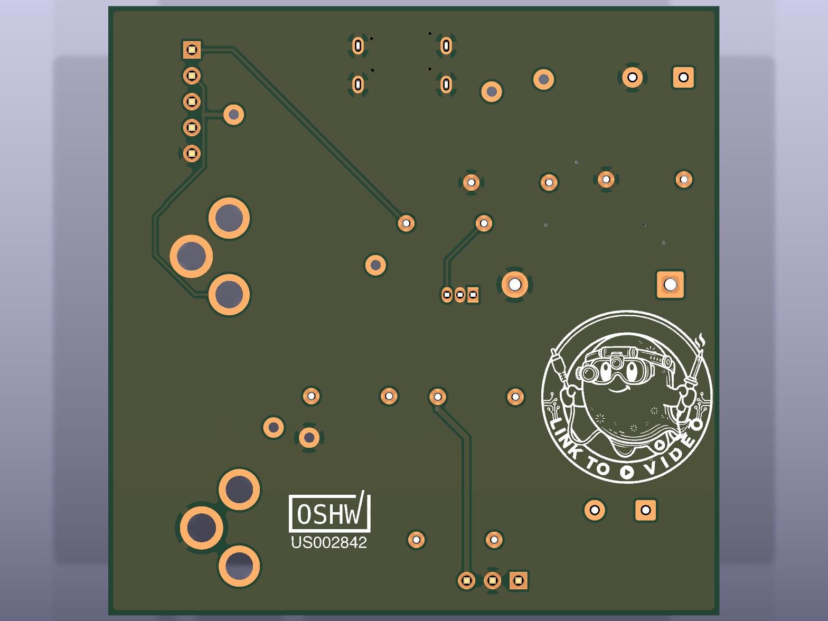
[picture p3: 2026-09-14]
pcb_bottom_final.png

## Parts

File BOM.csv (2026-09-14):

Reference | Description | Value | Package/Footprint | Mount | Manufacturer | Manufacturer Part Number | LCSC | Datasheet | Quantity | Supplier Link | Notes
C1 | Electrolytic capacitor | 100µF 16V | Radial THT | THT | Generic |  |  |  | 1 |  | Bulk cap on switched 5V rail to GND. Spec: 100 uF, >=16 V, aluminium electrolytic, radial, <=10 mm dia, 5.0 mm pitch. No MPN - any equivalent.
C2 | Electrolytic capacitor | 470µF 16V | Radial THT | THT | Generic |  |  |  | 1 |  | Coupling cap; blocks DC bias from Q1 emitter before RCA jack. 470µF not 100µF: into the 150Ω load (R5 75Ω + TV 75Ω) 100µF gives τ=15ms against the 16.7ms field period, which tilts the picture top-to-bottom. 470µF gives τ=70ms. Spec: 470 uF, >=16 V, aluminium electrolytic, radial, <=10 mm dia, 5.0 mm pitch. No MPN - any equivalent.
C3 | Ceramic capacitor | 100nF | 0805 SMD | SMD | YAGEO | CC0805KRX7R9BB104 | C49678 | https://www.lcsc.com/datasheet/C49678.pdf | 1 | https://www.lcsc.com/product-detail/C49678.html | X7R 16V+; U1 input decoupling - mount as close to U1 pin 1 as possible (TI datasheet requirement). Spec: 100 nF +/-10%, >=16 V, X7R, 0805 - any equivalent; the LCSC part above is a JLCPCB basic part.
D1 | TVS diode (1500W unidirectional) | 1.5KE6.8A | DO-201AE THT | THT | Littelfuse | 1.5KE6.8A | C294199 | https://www.littelfuse.com/assetdocs/littelfuse_tvs_diode_1_5ke_datasheet.pdf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 | 1 | https://www.digikey.com/en/products/detail/littelfuse-inc/1-5KE6-8A/285842 (Littelfuse) | https://www.lcsc.com/product-detail/C294199.html (DOWO) | VWM 5.80V / VBR 6.45-7.14V @10mA / VC 10.5V @144.8A (Littelfuse figures; the part actually fitted). Vishay's equivalent is 1.5KE6.8A-E3/54 - the plain 1.5KE6.8A MPN is Littelfuse's. Littelfuse packages it DO-201AA/DO-27 rather than DO-201AE; the 15.24 mm footprint takes either. Cathode (banded end) toward +5V - the KiCad symbol names both pins A1/A2 and shows no polarity, but the footprint silkscreen has the band. Clamps above U1 absolute max 7V, so it protects the NES, not the eFuse. LCSC stock of the 1.5KE6.8A is DOWO-branded (C294199, DO-201, MOQ 5, ~1,400 in stock 2026-09-09): VWM 5.8 V, VBR 6.46 V, VC 10.5 V @ 142.86 A - equivalent to the Littelfuse figures above, so every conclusion here still holds, including that D1 does not protect U1. Manufacturer/MPN still name Littelfuse because that is the part fitted on v1; 1.5KE6.8A is a generic type number, not a Littelfuse-only MPN. Order either.
F1 | PTC resettable polyfuse | 2A (IH=2.0A / IT=3.8A / VMAX=16V) | Radial disc THT | THT | Littelfuse | RHEF200 |  | https://www.littelfuse.com/assetdocs/resettable-ptc-rhef-datasheet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 | 1 | https://www.digikey.com/en/products/detail/littelfuse-inc/RHEF200/5130265 | Non-polarized; backup protection upstream of U1 eFuse. IH 2.0 A / IT 3.8 A / 16 V max / Imax 100 A, Rmin 45 mOhm / R1max 110 mOhm. REUSED FROM THE v1 BUILD - desoldered, not reordered. Deliberately NOT moved to LCSC: F1 is through-hole, so it is not on the SMD assembly BOM PCBWay sources, and the Littelfuse part beats the LCSC alternatives on every axis that matters (Imax 100 A vs 40 A, 3.8 A trip vs 4.0 A, ~9-10 mm body vs 15.2 mm). If it ever needs reordering, buy it from DigiKey or Mouser alongside the Switchcraft RCA jacks, which cannot come from LCSC either. Closest LCSC parts, for reference: Jinrui JK30-200 (C369104 - verified radial leaded, 5.1 mm pitch, but taller and only 40 A Imax) and JKSEMI JK16-200T (C5183874 - LCSC lists it as through-hole but its datasheet is headed 'JK16 Series Surface Mount PTC Devices' and LCSC has no land pattern drawn; package unconfirmed, do not use without checking the mechanical drawing). Footprint: no KiCad footprint exists for the Littelfuse RHEF series. F1 uses Fuse:Fuse_Bourns_MF-RG300 - pads at (0,0) and (5.1,1.2), 5.24 mm centre-to-centre, 1.01 mm drills. The RHEF200's 0.51 mm leads at 5.05 +/-0.75 mm spacing fit that, but the Bourns part is a 3.0 A/5.1 A device and the silkscreen outline is its body, not the RHEF200's - don't use it for clearance.
J2 | RCA phono jack, right-angle PCB mount (audio) | Audio | Right-angle THT, Switchcraft PJRA series | THT | Switchcraft | PJRAN1X1U03X |  | https://www.switchcraft.com/assets/1/24/PJRAN1X1U__X_SERIES_CD.PDF | 1 | https://www.mouser.com/en/ProductDetail/Switchcraft/PJRAN1X1U03X?qs=mcPJWgAPNrc45bmxqO8nXw%3D%3D | Audio pass-through from J4 pin 2 - the board does not amplify audio. Sleeve to GND. Mouser 502-PJRAN1X1U03X. Red-bodied part; order the colour you want.
J3 | RCA phono jack, right-angle PCB mount (video) | Video | Right-angle THT, Switchcraft PJRA series | THT | Switchcraft | PJRAN1X1U03X |  | https://www.switchcraft.com/assets/1/24/PJRAN1X1U__X_SERIES_CD.PDF | 1 | https://www.mouser.com/en/ProductDetail/Switchcraft/PJRAN1X1U03X?qs=mcPJWgAPNrc45bmxqO8nXw%3D%3D | Composite video output, fed from C2 through R5. Sleeve to GND - see the v1 fault where this sleeve was wired to the audio net.
J4 | Pin header 1x05, feed from the NES | Conn_01x05 | 2.54mm THT vertical | THT | Generic |  |  |  | 1 |  | Connection to the console: 1=video in, 2=audio in, 3=+5V out to the NES, 4/5=GND. Was missing from this BOM until 2026-08-28. Spec: 1x05 pin header, 2.54 mm, vertical THT. Suggested: LCSC C492404 (PZ254V-11-05P).
J5 | Pin header 1x03 | RGB conn feed | 2.54mm THT vertical | THT | Generic |  |  |  | 1 |  | Feed to the panel-mounted 8-pin mini-DIN RGB connector: 1=video/sync, 2=GND, 3=+5V. Connector itself ships with the NESRGB kit and mounts in the shell. Spec: 1x03 pin header, 2.54 mm, vertical THT. Suggested: LCSC C2937625 (PZ254V-11-03P).
Q1 | PNP transistor | 2SA733 | TO-92 THT | THT | UTC (Unisonic) | 2SA733L-P-T92-B | C5310429 | https://www.unisonic.com.tw/uploadfiles/836/part_no_pdf/2SA733.pdf | 1 | https://www.lcsc.com/product-detail/C5310429.html | Flat side facing viewer, leads down = E-C-B left to right. Base=video in (through R2), Emitter=R1/C2 node, Collector=GND. Replaces the 2SA1015/KSA1015, which are both End of Life (checked 2026-08-29): MCC 2SA1015-GR-AP is stocked at Mouser but EOL, and every onsemi KSA1015 reads Obsolete on DigiKey, available only through Rochester. The 2SA733 is in production, shares the E-C-B pin order exactly, and is a better part for a video buffer: fT 190 MHz typ vs 80 MHz, Cob 2-3 pF, PC 750 mW, same VCEO -50 V / IC -150 mA / VEBO -5 V. Rank P is hFE 200-400, which matches the ~46 uA base current measured on the bench, so the bias point does not move. DigiKey's Renesas 2SA733 is Rochester stock at $1.90 - buy the UTC part from LCSC at $0.035 instead. Do NOT substitute a 2N3906 or BC557 on this board: both are electrically fine here but put the BASE in the middle pin where this footprint wants the COLLECTOR, and no rotation fixes that. Pin order is a manufacturer's choice - check the datasheet of the brand you actually buy.
R1 | Resistor | 220Ω | THT | THT | Generic |  |  |  | 1 |  | Q1 emitter load: one end +5V, other end to Q1 emitter/C2 node. Not both ends to +5V. Lowered from 300Ω for v2 to raise the drive current: at the assumed ~1.3V base, 300-330Ω supplies only ~6.2mA at peak white against the ~6.7mA the 150Ω load needs. 220Ω gives ~9.3mA and real headroom. Retune if the measured DC at J4.1 differs from ~1.3V. Spec: 220 ohm +/-5%, >=0.25 W, axial THT 7.62 mm pitch. No MPN - any equivalent.
R2 | Resistor | 330Ω | Axial THT DIN0207 P7.62mm | THT | Generic |  |  |  | 1 |  | Series resistor between J4.1 (video in from NES) and Q1's base. Mirrors the 330Ω Nintendo places in the same position. Negligible signal loss against Q1's ~21kΩ base input impedance; limits fault current into the base-emitter junction, whose reverse rating is only 5V. New in v2. Spec: 330 ohm +/-5%, >=0.25 W, axial THT 7.62 mm pitch. No MPN - any equivalent.
R3 | Resistor | 5.1kΩ | THT | THT | Generic |  |  |  | 1 |  | CC1 pulldown; measured 5.07kΩ. Spec: 5.1 kohm +/-5%, >=0.1 W, axial THT 7.62 mm pitch. No MPN - any equivalent.
R4 | Resistor | 5.1kΩ | THT | THT | Generic |  |  |  | 1 |  | CC2 pulldown; measured 5.13kΩ. Spec: 5.1 kohm +/-5%, >=0.1 W, axial THT 7.62 mm pitch. No MPN - any equivalent.
R5 | Resistor | 75Ω | THT | THT | Generic |  |  |  | 1 |  | Video series termination; populated on the fabbed v1 board. Spec: 75 ohm +/-1%, >=0.25 W, axial THT 7.62 mm pitch. No MPN - any equivalent.
R6 | Resistor | 22k | 0805 SMD | SMD | UNI-ROYAL | 0805W8F2202T5E | C17560 | https://www.lcsc.com/datasheet/C17560.pdf | 1 | https://www.lcsc.com/product-detail/C17560.html | Sets U1 current limit. I_OS = 25.9/R_ILIM(kohm) -> ~1.18A typ. Higher R = LOWER limit. Valid range 15k-232k. Spec: 22 kohm +/-1%, 0805 - keep the 1% tolerance, it sets the current limit. JLCPCB basic part.
R7 | Resistor | 75 Ohm | Axial THT DIN0207 P7.62mm | THT | Generic |  |  |  | 1 |  | Series source termination for the mini-DIN RGB connector video pin (mirrors R5 for the RCA jack). Spec: 75 ohm +/-1%, >=0.25 W, axial THT 7.62 mm pitch. No MPN - any equivalent.
TP1-TP4 | Test point (through-hole pad) |  | 2.0mm pad / 1.0mm drill THT | - | Not a purchased part |  |  |  | 4 |  | Not a purchased part — bare plated holes for bring-up (video, GND, +5V, audio). Optionally fit 0.64mm square header pins for scope grabbers.
U1 | Current-limited power switch (eFuse) | TPS2553DBVR | SOT-23-6 SMD | SMD | Texas Instruments | TPS2553DBVR | C55266 | https://www.ti.com/lit/ds/symlink/tps2553.pdf | 1 | https://www.lcsc.com/product-detail/C55266.html | Adjustable OCP between F1 and the 5V rail. EN (pin 3) active-high tied to IN. Auto-retry version (the -1 suffix is latch-off). FAULT (pin 4) left unconnected. Sourcing checked 2026-09-07: DigiKey 0 stock (all pack types), Mouser 0 stock with a 112-day factory lead. LCSC has 44,248 @ $0.298 - buy U1 from LCSC, and tell PCBWay to source it there rather than a Western distributor.
USB-C1 | USB-C receptacle | USB4125-GF-A-0190 | SMD | SMD | Global Connector Technology (GCT) | USB4125-GF-A-0190 | C5246813 | https://gct.co/files/drawings/usb4125.pdf | 1 | https://www.lcsc.com/product-detail/C5246813.html | 6-pin power-only (VBUS x2, GND x2, CC1, CC2); no data lines. 48 V / 3 A, 20,000 mating cycles. Replaces GCT USB4970-00-A, which LCSC does not stock - searching that MPN on LCSC will always come up empty. The USB4125 is a different GCT line number that LCSC does carry, and the board was already laid out to its land pattern, so this is a sourcing change with no layout change. Footprint: Connector_USB:USB_C_Receptacle_GCT_USB4125-xx-x-0190_6P_TopMnt_Horizontal - byte-identical in copper, silk, fab, courtyard and drills to the plain USB4125-xx-x footprint the board was drawn with; only the name, descr and 3D model differ. The -0190 suffix is the 1.90 mm shell stake, which protrudes 0.30 mm through this 1.6 mm board and gives a bottom-side fillet; the 1.00 mm stake (plain USB4125-GF-A, LCSC C3151650) does not reach through. Sourcing checked 2026-09-09: LCSC C5246813 ~630-3,670 depending on source, MOQ 1, $0.85. Stock is thin next to the generic Chinese 6P parts, so order spares.

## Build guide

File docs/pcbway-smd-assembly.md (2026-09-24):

# Ordering SMD-only assembly from PCBWay

This board is mostly through-hole. Only four parts reflow, and all four are on the
top side, so PCBWay can do a single-sided SMT run and ship boards with the fiddly
parts already placed. The through-hole half stays ordinary hand-soldering.

This document covers that order. The tooling regenerates the files themselves for
each run; see [Regenerating the package](#regenerating-the-package).

## The split

| | Parts | Who fits them |
|---|---|---|
| **SMD (PCBWay)** | C3, R6, U1, USB-C1 | reflowed, top side only |
| **Through-hole (you)** | C1, C2, D1, F1, J2, J3, J4, J5, Q1, R1, R2, R3, R4, R5, R7 | hand-soldered after delivery |

The order has four placements over four distinct part numbers. An assembly order does
not get much smaller than this.

TP1–TP4 are bare plated holes, not parts. The BOM and the placement file exclude them.

## USB-C1 is Hybrid, not SMD

The Type-C receptacle has ten pads: six SMD signal pads and **four through-hole shell
stakes**. The shell stakes sit on `F.Paste`, so they are *pin-in-paste*. The stencil
deposits paste into the holes, and the stakes reflow in the same pass as everything
else, with no separate operation and no hand-soldering.

The BOM lists the part as `Hybrid` in the Type column for exactly this reason. If it
said `SMD`, an assembler would have every reason to place the part and leave the four
mechanical anchors dry, so six 0.7 mm signal pads would end up holding the connector
that takes all the insertion force.

> [!CAUTION]
> **Tell PCBWay to paste and reflow the four shell stakes with the SMD pass.**
> If they quote this part as through-hole assembly or ask about the shell pins, the
> answer is the same.

## Sourcing

PCBWay turnkey sources by MPN from wherever they can. All four SMD lines are
now LCSC parts — checked 2026-09-09:

| Ref | MPN | Status |
|---|---|---|
| C3 | `CC0805KRX7R9BB104` | LCSC C49678 — basic part, 7.2 M in stock, $0.015 |
| R6 | `0805W8F2202T5E` | LCSC C17560 — basic part, 449 k in stock, $0.0035 |
| **U1** | `TPS2553DBVR` | **DigiKey 0, Mouser 0 (112-day factory lead). LCSC C55266 has 44 k @ $0.298 — insist on LCSC.** |
| **USB-C1** | `USB4125-GF-A-0190` | LCSC C5246813 — ~630–3,670 in stock, MOQ 1, $0.85. **From v2 this replaces the `USB4970-00-A`, which LCSC does not stock**; the USB4125 is a different GCT line number that LCSC carries, and the board was already laid out to its land pattern. Stock is thin, so tell them to buy spares. |

U1 is the part that can quietly wreck a schedule. It's a live, in-production TI part,
but Western distribution is empty right now: the factory lead is close to four months,
while LCSC holds 44,000 of them. Put the LCSC part number in front of PCBWay rather
than letting them quote it blind.

The LCSC column in the assembly BOM makes that easy. It isn't part of PCBWay's
expected format, and they'll ignore it if they prefer their own source.

Substitution rules worth passing on:

- **R6 must stay ±1%.** It sets the eFuse current limit (`I_OS = 25.9 / R_kΩ`), so
  a 5% part won't do.
- **U1 must be `TPS2553`, not `TPS2552` or any `-1` suffix.** The TPS2552 has an
  active-low enable and the TPS2553 an active-high one, and `-1` is the latch-off
  variant. This board ties EN high and needs auto-retry.
- **C3 is ordinary.** Any ≥16 V X7R 0805 will do.

## What to upload

From the newest `pcbway_production/<timestamp>/` directory, upload these files:

| File | Purpose |
|---|---|
| `gerbers/` + `drill/` | fabrication |
| `assembly_bom_smd.csv` | the four SMD lines, PCBWay turnkey column order |
| `assembly_cpl_smd.csv` | placements for those four only |
| `manifest.json` | what was checked, and the hashes it was checked against |

> [!CAUTION]
> **Do not upload `bom.csv` and `cpl.csv`.** Those two files in the same directory
> cover the **whole board**, all 19 parts. They're right for a fully assembled order
> and wrong here: uploading them asks PCBWay to source and fit the through-hole parts
> too. Use the `_smd` pair.

Order settings: 2 layers, 59.9 × 59.7 mm, 1.6 mm, assembly **top side only**,
minimum 5 boards. PCBWay quotes assembly manually, so expect 1–2 business days before
you see a price, which is the main scheduling difference from JLCPCB.

## Fabrication notes

The board sits well inside PCBWay's standard process: minimum track 0.2 mm and
clearance 0.2 mm against their 0.1 mm capability, minimum drill 0.3 mm against
0.15 mm. Nothing here needs an advanced-process surcharge.

One DFM point worth knowing rather than acting on: C3, R6 and U1 use KiCad's
`HandSolder` / `Handsoldering` footprint variants, whose lands extend further
out than the IPC nominal. They reflow fine — PCBWay builds these every day — but
they take more paste than the nominal land would, which is a mild tombstoning
risk on the two 0805s. The footprints were chosen so the board stays
hand-assemblable, which is the right trade for this project. If a future
revision ever goes fully machine-assembled, switching those three to the
standard variants is the cleanup.

You only need a framed stencil if you plan to reflow boards yourself, not for a
PCBWay assembly order.

## Regenerating the package

The gate refuses to package a board that has not passed DRC and schematic
parity, so this is also the verification step. `prefab_gate` comes from
[danielboston38/prefab-gate](https://github.com/danielboston38/prefab-gate),
which is a separate tool rather than part of this project:

```bash
export KICAD_CLI=/Applications/KiCad/KiCad.app/Contents/MacOS/kicad-cli
python3 tools/check_nets.py
prefab_gate package nes_power_video.kicad_pcb --out pcbway_production
python3 tools/pcbway_assembly.py nes_power_video.kicad_pcb pcbway_production/<new-timestamp>
```

`pcbway_assembly.py` reads the mount type from the board's own `(attr ...)` and
pad list rather than a hand-kept list of designators, so a part that changes
mounting — or a new SMD part — lands on the correct side of the split without
anyone remembering to update it. It refuses to write anything if an SMD part has
no MPN, since that is the field PCBWay sources by, and it prints whether the SMD
parts span one side or two.

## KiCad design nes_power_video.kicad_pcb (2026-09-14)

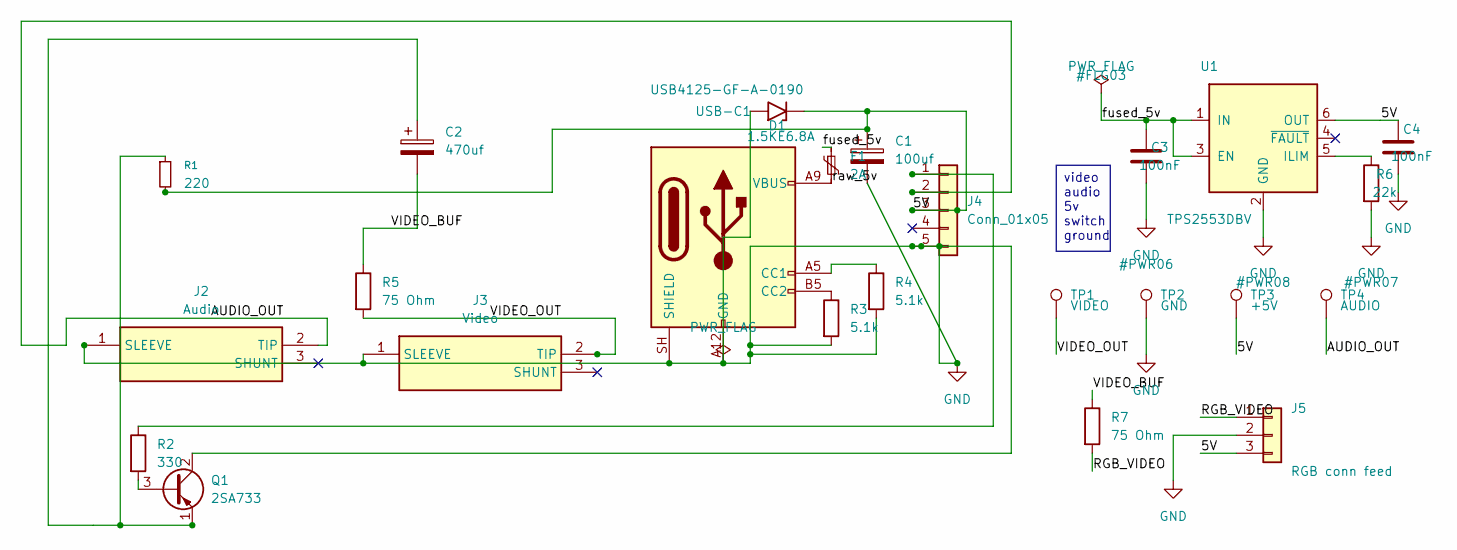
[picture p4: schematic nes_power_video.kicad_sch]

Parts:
C1: 100uf; CP_Radial_D10.0mm_P5.00mm
C2: 470uf; CP_Radial_D10.0mm_P5.00mm
C3, C4: 100nF; C_0805_2012Metric_Pad1.18x1.45mm_HandSolder; MPN CC0805KRX7R9BB104; LCSC C49678
D1: 1.5KE6.8A; D_DO-201AE_P15.24mm_Horizontal; MPN 1.5KE6.8A; LCSC C294199
F1: 2A; Fuse_Bourns_MF-RG300; MPN RHEF200
J2: Audio; PJRAN1X1U03X; Mouser Part Number 502-PJRAN1X1U03X
J3: Video; PJRAN1X1U03X; Mouser Part Number 502-PJRAN1X1U03X
J4: Conn_01x05; PinHeader_1x05_P2.54mm_Vertical
J5: RGB conn feed; PinHeader_1x03_P2.54mm_Vertical
Q1: 2SA733; TO-92_Inline; MPN 2SA733L-P-T92-B; LCSC C5310429
R1: 220; R_Axial_DIN0207_L6.3mm_D2.5mm_P7.62mm_Horizontal
R2: 330; R_Axial_DIN0207_L6.3mm_D2.5mm_P7.62mm_Horizontal
R3, R4: 5.1k; R_Axial_DIN0207_L6.3mm_D2.5mm_P7.62mm_Horizontal
R5, R7: 75 Ohm; R_Axial_DIN0207_L6.3mm_D2.5mm_P7.62mm_Horizontal
R6: 22k; R_0805_2012Metric_Pad1.20x1.40mm_HandSolder; MPN 0805W8F2202T5E; LCSC C17560
TP1: VIDEO; TestPoint_THTPad_D2.0mm_Drill1.0mm
TP2: GND; TestPoint_THTPad_D2.0mm_Drill1.0mm
TP3: +5V; TestPoint_THTPad_D2.0mm_Drill1.0mm
TP4: AUDIO; TestPoint_THTPad_D2.0mm_Drill1.0mm
U1: TPS2553DBV; SOT-23-6_Handsoldering; MPN TPS2553DBVR; LCSC C55266
USB-C1: USB4125-GF-A-0190; USB_C_Receptacle_GCT_USB4125-xx-x-0190_6P_TopMnt_Horizontal; MPN USB4125-GF-A-0190; LCSC C5246813

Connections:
/5V: C1.1, C4.1, D1.1 (A1), J4.3, J5.3, R1.2, TP3.1, U1.6 (OUT)
/AUDIO_OUT: J2.2 (TIP), J4.2, TP4.1
/RGB_VIDEO: J5.1, R7.2
/VIDEO_BUF: C2.2, R5.1, R7.1
/VIDEO_OUT: J3.2 (TIP), R5.2, TP1.1
/fused_5v: C3.1, F1.1, U1.1 (IN), U1.3 (EN)
/raw_5v: F1.2, USB-C1.A9 (VBUS), USB-C1.B9 (VBUS)
GND: C1.2, C3.2, C4.2, D1.2 (A2), J2.1 (SLEEVE), J3.1 (SLEEVE), J4.5, J5.2, Q1.2 (C), R3.2, R4.2, R6.2, TP2.1, U1.2 (GND), USB-C1.A12 (GND), USB-C1.B12 (GND), USB-C1.SH (SHIELD)
unnamed: J4.1, R2.1
unnamed: Q1.3 (B), R2.2
unnamed: C2.1, Q1.1 (E), R1.1
unnamed: R6.1, U1.5 (ILIM)
unnamed: R4.1, USB-C1.A5 (CC1)
unnamed: R3.1, USB-C1.B5 (CC2)

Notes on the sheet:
video audio 5v switch ground

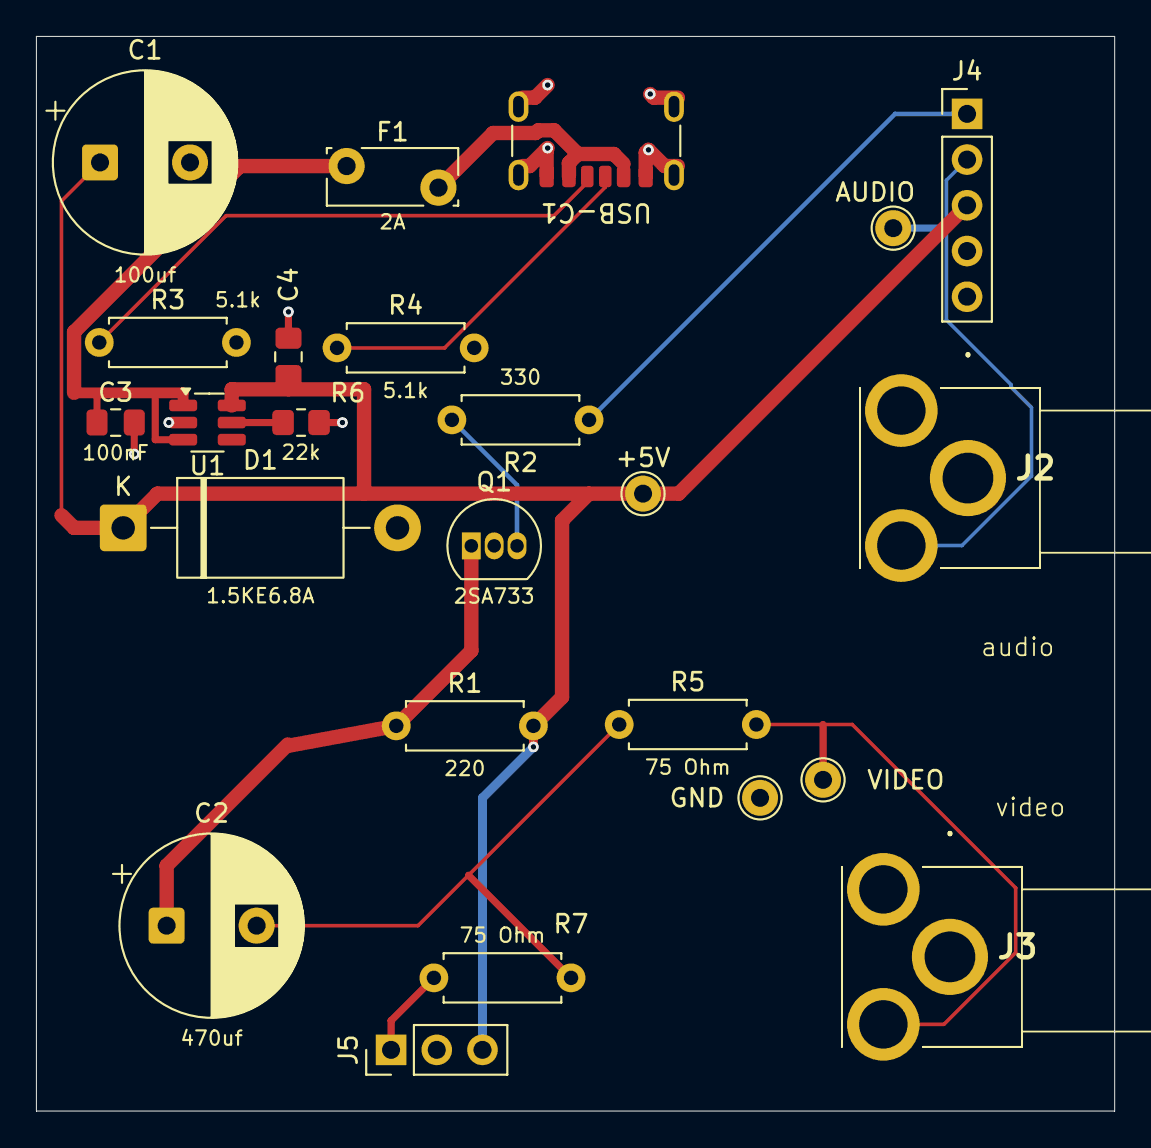
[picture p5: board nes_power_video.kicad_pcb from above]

Board: 2 copper layers, 59.9 x 59.7 mm, 24 parts (0 on the bottom side), 14 nets.

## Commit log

2026-09-07 feat(bom): carry sourcing metadata on the board, and split out an SMD-only fab package
    The PCBWay BOM is exported from the board, but every sourcing field lived only
    on the schematic symbols, so the MPN column came out empty for all but J2 and
    J3 — and those two only because they still carried the legacy
    Manufacturer_Part_Number field. MPN is the field PCBWay sources by, so the
    package could not have been assembled as exported.
    Copy Manufacturer, MPN, LCSC, Spec, Supplier Link, Datasheet and Description
    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
    [BOM.csv, assembly_bom_smd.csv, bom.csv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]
2026-09-07 chore: stop tracking generated output, keep only the KiCad source
    The repository was carrying its own build products: three PCBWay fab packages,
    a root gerber job file, a board zip, and nes_power_video.kicad_prl — which is
    per-user KiCad UI state (open tabs, zoom) and changes on every session, so it
    turns up as noise in diffs that have nothing to do with it.
    None of it is source. The board and schematic are; everything above is derived
    from them, and the gate reproduces a package in one command. Tracking a stale
    copy alongside is worse than not having one, because the stale copy is the one
    somebody uploads by mistake.
    Untrack them and ignore, along with the local files that accumulate be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
    [assembly_bom_smd.csv, bom.csv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]
2026-09-07 chore: ignore KiCad-Diff output
    `kidiff` writes .kidiff/ into the repo: a checkout of the board and schematic
    at each commit being compared, a layer SVG per side, and the web gallery. It
    is regenerated on every run and reached 2.2 MB after a single two-commit diff.
    Claude-Session: https://claude.ai/code/session_01PtxfjLc74W7S5b4xuajgSz
2026-09-07 docs: design for shipping prefab-gate as a KiCad plugin
    The gate is deterministic — kicad-cli DRC, zone refill, schematic parity, and
    a classifier. No model is in the loop, so the audience is every KiCad user,
    not only the ones running Claude Code. Today it ships only as a Claude Code
    plugin inside a hardware repo about an NES video board, which is the wrong
    shelf for it.
    Three decisions shape the design. The button checks and reports but never
    packages, because the gate's guarantee rests on hashing a file nobody is
    editing, and the board on screen can differ from the board on disk at any
    moment. The tool moves to its own repository, which KiCad separately requires
    anyway — packages mus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
2026-09-07 docs: implementation plan for the prefab-gate KiCad plugin
    Eight tasks. Six are local and reversible; the last two create a public
    repository and a public submission, and both stop for Mark.
    Self-review caught three bugs worth fixing on paper rather than in KiCad. The
    shipped modules now use relative imports: PCM installs the package under a
    directory of its own choosing, so an absolute `from plugin import ...` works in
    the repo and breaks in the field. The gate is located by trying a sibling
    first and the repo's ../../scripts second, because the installed layout is flat
    and the repo's is not.
    The plan deviates from the spec in one place, flagged in it: staging does not
    refuse a project wi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
2026-09-07 docs: confirm plugins/ may contain subdirectories
    The addon documentation says plugin code goes in plugins/ "directly here, no
    subdirectories", which would have forced the gate package to be vendored as
    flat prefixed modules. It does not mean that.
    Settled by downloading a published package instead of re-reading the prose.
    InteractiveHtmlBom, in KiCad's official repository, ships plugins/ with five
    subdirectories, nested Python packages two levels down
    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
2026-09-07 docs: choose SWIG ActionPlugin over the IPC API, and fix the submission address
    Two corrections to the plan and one recorded decision.
    The submission address was right the first time: merge requests go to
    gitlab.com/kicad/addons/metadata. The restriction is narrow and I over-read it
    — it forbids submitting to addons/repository, the generated repository, not the
    metadata source. The warning claiming the documented URL was "presumed wrong"
    is removed; the stop-and-ask before submitting stays, because the submission is
    public and cannot be recalled.
    On the IPC API introduced in KiCad 9.0: not for v0.1. The gate's floor is 8.0,
    where kicad-cli gained --schematic-parity, and IPC would raise t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
2026-09-07 feat(kicad-plugin): stage a minimal project copy for DRC
    DRC rewrites the board to refill zones, so a plugin must never point it at the
    file open in the editor. Staging copies a four-file whitelist to a temp
    directory instead: the board, every schematic sheet, and the .kicad_pro and
    .kicad_dru that carry severities and custom rules.
    The whitelist is the point. 3D models and libraries are excluded because
    footprints and symbols are embedded in the board and schematic, and they are
    what make projects large — 0.41 MB staged against a 79 MB directory.
    Omitting .kicad_pro or .kicad_dru would be the subtle failure: DRC would fall
    back to default rules and return a confident verdict about a dif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
2026-09-07 feat(kicad-plugin): run the gate on a staged copy
    Calls prefab_gate.main so the GUI and the CLI share one implementation of the
    policy. Under --json the gate emits only the verdict on stdout and everything
    else on stderr, so parsing stdout is a contract rather than screen-scraping —
    and a test pins that the runner really does ask for --json, because a plain
    `check` would put prose on the stream being parsed.
    Stale zone fills are detected by hashing the staged board either side of the
    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
2026-09-07 feat(kicad-plugin): add the toolbar action and its dialog text
    Splits the wording out of the wx layer, departing from the plan. summarise()
    was to live in action.py, which imports pcbnew and wx and therefore cannot be
    imported outside KiCad — so the text carrying the spec's two obligations would
    have been the one part with obligations and no tests. It lives in summary.py
    instead, with nine tests.
    Those obligations, now pinned: the dialog always names the file it read and
    when it was last saved, because unsaved editor changes cannot be detected
    reliably from a plugin and showing the facts beats guessing; and stale zone
    fills are reported rather than silently repaired, because the CLI fixes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
2026-09-07 feat(kicad-plugin): add the PCM and toolbar icons
    Two are required and they are different sizes: 64x64 for the manager's listing
    and 24x24 for the pcbnew toolbar button. A shield with a bar across it —
    verification, and a thing that stays shut.
    Generated from stdlib zlib and struct rather than committed as opaque binaries
    with no source, and without an image library KiCad's bundled Python cannot
    install. Both render correctly and stay legible at toolbar size; the generator
    is committed so they can be regenerated or adjusted rather than reverse
    engineered.
    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
2026-09-07 feat(kicad-plugin): build the PCM archive, and stage the library tables
    Assembles KiCad's expected layout — metadata.json at the root, plugin code and
    the gate package under plugins/, a 64x64 resources/icon.png — and computes
    download_sha256, download_size and install_size rather than leaving three
    numbers to be kept in step by hand with the artifact they describe. Those
    fields go only into the submission copy; the spec forbids them inside the
    archive, which is easy to break by copying one file to both places, so a test
    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
2026-09-07 test(kicad-plugin): verified in KiCad 10.0.6 via a real PCM install
    Installed from file through the Plugin and Content Manager and run against
    nes_power_video.kicad_pcb. The dialog rendered, reported PASSED with the same
    6 cosmetic silkscreen findings the CLI reports in place, and git status was
    empty afterwards — the board was not touched, which is the promise the whole
    design exists to keep.
    Settles the last open question with evidence rather than reading. PCM strips
    the plugins/ wrapper and copies its contents into a directory named from the
    identifier with dots replaced by underscores:
    3rdparty/plugins/com_github_danielboston38_prefab-gate/
    __init__.py action.py runner.py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
2026-09-07 chore: prefab-gate moves to its own repository
    The gate is a general-purpose KiCad tool with its own audience and its own MIT
    licence, sitting inside a CERN-OHL-S hardware project about an NES video board.
    That was the wrong shelf, and KiCad's addon repository independently requires
    source hosted somewhere with issue tracking, so the split had to happen before
    it could be submitted.
    Now at danielboston38/prefab-gate, moved with `git subtree split` so all 40
    commits keep their authorship and messages rather than arriving as one squashed
    import. Verified from a clean clone of the published repository: 228 tests pass
    and the PCM archive builds standalone.
    The marketplace manifest stays here r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
2026-09-07 fix(pcb): put the raw and fused 5V rails in the Power netclass
    The netclass patterns were /5V*, GND* and VBUS. The two rails that carry the
    board's full input current are named /raw_5v and /fused_5v, so they matched
    none of them and silently inherited Default — 0.2 mm track width instead of
    Power's 0.8 mm.
    That is how the USB-C VBUS input ended up 0.2 mm wide for 7.9 mm of its length.
    On 1 oz outer copper IPC-2221 rates that at 0.74 A for a 10 C rise and 1.00 A
    for 20 C, while F1 (RHEF200) holds 2.0 A and does not trip until 3.8 A. The
    polyfuse cannot protect the conductor it feeds: at F1's hold current the trace
    sits around a 97 C rise, so the trace is the fuse.
    This commit fixes the ca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
2026-09-08 fix(pcb): reroute /raw_5v out of the 0.2mm bottleneck past USB-C1
    The VBUS input from USB-C1 to F1 previously ran 7.9mm at 0.2mm track width
    through a corridor between USB-C1's ground pads and an adjacent CC2 track -
    undersized for F1's 2A hold / 3.8A trip rating on 1oz copper.
    Fix has two parts:
    - Tightened the Power netclass clearance 0.2mm -> 0.15mm, which opened just
    enough margin in that corridor to route the full path at 0.8mm, with only
    two short (0.68mm, 0.71mm) 0.2mm neck-downs directly at the pads where no
    more room exists. Total narrow-gauge length dropped from 7.9mm to 1.47mm,
    and it's now sandwiched between wide copper rather than in series across
    the whole span.
    -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
    [nes_power_video.kicad_pcb]
2026-09-08 docs: mark the KiCad plugin plan/spec as implemented
    Both documents still read as if the work hadn't started. It shipped: built,
    verified against KiCad 10.0.6, split into danielboston38/prefab-gate, and the
    board repo updated to point at it. Checked off Tasks 1-7 (38 of 42 steps) and
    updated the spec's status header accordingly.
    Left unchecked, correctly: Task 8, the PCM registry submission, which has not
    happened and needs Mark's go-ahead per its own stop-and-ask note.
    Claude-Session: https://claude.ai/code/session_01WYRpQwnwUmWdzqXMnPsmkw
2026-09-08 docs: explain the three stale ERC exclusions instead of leaving them silent
    The blind-test review correctly flagged these as undocumented cruft. Rather
    than remove them, each now carries the actual reason it was dismissed:
    - J4 pin 4: genuinely unconnected, a deliberately unused redundant GND pin
    (pin 5 carries the real connection). Verified against the netlist.
    - USB-C1 CC1/CC2 (A5/B5): genuinely connected to their 5.1k pulldowns (R4/R3).
    ERC's pin_not_connected check flags them regardless of the real wiring --
    a false positive, re-verified against kicad-cli's netlist export.
    Left the exclusions in place rather than clearing them. Removing the CC1/CC2
    ones would reintroduce two perm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
2026-09-08 fix(erc): remove three ERC exclusions that no longer fire at all
    Corrects 8b0d1a1, which was wrong. That commit documented these three
    exclusions as legitimate ongoing dismissals -- a genuinely-unused J4 pin 4
    and two USB-C1 CC pins it called ERC false positives. Verified by testing
    removal directly rather than trusting the earlier analysis: with all three
    exclusions cleared, ERC reports zero violations. None of them fire any more.
    What actually happened: J4 pin 4 already has a real no_connect flag placed
    correctly at its electrical connection point -- confirmed on screen, and
    confirmed by matching KiCad's own reported cursor position against the
    exclusion's stored coordinate. My original c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
2026-09-09 docs: safety advisory for the undersized VBUS input trace on all fabbed boards
    Every board ever fabricated for this project reaches F1 from the USB-C
    receptacle through 9.06 mm of 0.2 mm-wide trace on 1 oz copper. Both PCBWay
    packages (2026-07-07 and 2026-07-16) carry it; verified by walking copper
    connectivity in the shipped Gerbers rather than from KiCad source, so the
    figure describes physical boards. The as-fabbed run is slightly worse than the
    7.95 mm the repo carried just before the fix.
    The defect is the trace relative to the fuse behind it. Electrothermal
    simulation (ngspice, distributed model validated against IPC-2221 to within
    8% and cross-checked with Onderdonk) puts the as-fabb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
2026-09-09 sim: publish the electrothermal harness behind the VBUS advisory
    A safety advisory that cites simulation results should ship the simulation.
    Adds a self-contained harness that regenerates every figure in the advisory:
    the model and its IPC-2221 calibration, geometry extraction by connectivity
    from both .kicad_pcb and Gerber sources, and a runner covering validation,
    steady state, damage thresholds, the trace-vs-fuse race, and the sensitivity
    sweep. ngspice plus the Python standard library, about two minutes to run.
    Consolidating the throwaway scripts into a reviewable harness surfaced three
    defects in them, one of which changes a published claim:
    - The USB-C tap node was computed but never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
2026-09-10 sourcing(v2): move USB-C1, F1 and D1 to LCSC parts
    Closes the last non-LCSC lines on the v2 BOM so the whole SMD assembly
    BOM can be sourced from one place, which is what U1's Western stockout
    forced in the first place.
    USB-C1: GCT USB4970-00-A -> USB4125-GF-A-0190 (LCSC C5246813).
    LCSC does not stock the USB4970 at all, so searching that MPN was always
    going to come up empty. The USB4125 is a different GCT line number that
    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
    [BOM.csv, nes_power_video.kicad_pcb, nes_power_video.kicad_sch]
2026-09-10 sourcing(v2): keep the RHEF200 for F1 rather than moving it to LCSC
    F1 does not belong in the LCSC consolidation. The constraint that drove
    this was U1 being unobtainable in the West, which matters because PCBWay
    sources the SMD assembly BOM -- C3, R6, U1, USB-C1 -- from one supplier.
    F1 is through-hole and is not on that BOM. Neither is D1. Both are hand
    -fitted parts that can come from anywhere, and a Mouser order is happening
    regardless because the Switchcraft RCA jacks are not an LCSC line and
    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
    [BOM.csv, nes_power_video.kicad_pcb, nes_power_video.kicad_sch]
2026-09-13 fix(pcb): silence logo parity, drop a duplicate /5V track, add review config
    Three unrelated cleanups that all surfaced from one prefab-gate run.
    The two silkscreen logos (Mascot_Link_To_Video, OSHW_US002842_Stacked)
    had no schematic symbol, so KiCad's parity check reported them as
    "Extra footprint" and prefab-gate blocked on it. They are board
    graphics, not parts: adding board_only ("Not in schematic") is how
    KiCad's own stock LayerMarker_* footprints handle this. Applied to
    both placed instances and to all three library footprints so
    re-placing one does not reintroduce the finding.
    /5V carried a duplicate track: 584a3ce2 ran (19.69,26.8423) ->
    (19.69,44.4547) laid directly over 47a13880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
    [nes_power_video.kicad_pcb]
2026-09-13 feat(power): add C4, a local 100nF bypass at the eFuse output
    TI's TPS2553 layout guidelines (SLVSBM8, 12.1) ask for "a high-value
    electrolytic capacitor and a 100-nF bypass capacitor on the output pin
    when large transient currents are expected". /5V had neither locally.
    C3 (100nF) bypasses the eFuse *input*; C1 (100uF) is the only thing on
    the output and sits ~52mm of copper away, reached by a 20.5mm 0.2mm
    spur that lands on D1's cathode pad. That routing is a fossil: C1
    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
    [nes_power_video.kicad_pcb, nes_power_video.kicad_sch]
2026-09-13 chore: keep only the suppressions an analyzer actually applies
    In kicad-happy 2.2.1 only analyze_emc.py and analyze_thermal.py call
    apply_suppressions. analyze_schematic.py and analyze_pcb.py load the
    config and never apply it, so the PM-002, UC-001, UC-002, RS-001 and
    SS-002 entries were dead weight that read as active policy. Dropping
    them rather than leaving config that silently does nothing.
    GP-001 and IO-001 stay because EMC does honour them: 11 of 18 findings
    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
2026-09-13 assets: track the source art for the two logo footprints
    Both footprints committed in 2987996 were generated from artwork that
    was never tracked, leaving the KiCad polygons as the only copy.
    mascot.svg carries 86 paths against Mascot_Link_To_Video.kicad_mod's
    86 fp_poly, so it is the direct source. That matters more than usual
    here: KiCad decimated the placed instance from 9809 vertices to 2222
    on save, so the board copy is a quarter of the original resolution and
    is not a viable master to re-derive from.
    certification-mark-US002842-wide.svg is the OSHW mark behind
    OSHW_US002842_Wide.kicad_mod; its -stacked sibling was already tracked,
    so this one was simply missed.
    Also removes a byte-id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
2026-09-13 fix(pcb): remove every overlapping track, and anchor C4's /5V connection
    A geometric sweep for collinear same-net overlap found five pairs, not
    the one spotted by eye in 2987996. Same-net overlap is invisible to
    DRC, so none of these were ever reported.
    /5V 3.00mm b7a635ae sat entirely inside the y=43.1 trunk
    /VIDEO_BUF 3.96mm 0d07e40b sat entirely inside a94ae6b3
    GND 1.27mm 4d3f7556 spanned what 387e46eb + 67cc2dcf already
    GND 0.14mm the tail of that same knot
    /fused_5v 0.60mm da31efaa doubled back over 1f43262f
    The GND knot is resolved by deleting the single full-span segment
    rather than the two-piece chain: 56acf260 lands on the intermediate
    poi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
    [nes_power_video.kicad_pcb]
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2026-09-13 assets: track the corrected mascot artwork
    mascot_link_to_video.png is the edited master -- the version with the
    wording fix -- and is now the only copy of it that exists. The
    unedited generation still carries the error, so this file is not
    recoverable by regenerating.
    It is the source mascot.svg was traced from (86 paths -> the 86
    fp_poly in Mascot_Link_To_Video.kicad_mod), which makes it the
    starting point for any future re-trace. That matters because KiCad
    decimated the placed instance from 9809 vertices to 2222 on save, so
    neither the board nor the footprint is a viable master to work back
    from.
    Claude-Session: https://claude.ai/cod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
2026-09-14 docs: credit PCBWay's fab sponsorship and record the GPL v3 dual grant
    The 2026-08-26 fab package, ordered 2026-08-27, was manufactured under a
    PCBWay sponsorship. Adds a section under Hardware thanking them, links the
    project's page on their community site, and fills in the previously empty
    Acknowledgments section.
    Two corrections fell out of dating it:
    - The sponsored run is the 2026-08-26 package, not the 2026-09-07 one that
    is the newest in git. That package was never committed, but f672f8d
    verified its copper and outline gerbers byte-identical to the fixed board
    with all 49 drill hits matching - so the zone fill and stale /AUDIO_OUT
    stub fixed the next day are not on these boa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
2026-09-17 docs: rewrite the README in the style of Simplified Technical English
    Procedures and warnings follow the ASD-STE100 procedural rules. Descriptive
    sections follow the structural rules. Rationale, status, credits and the
    2N3906/2SA1015 part history keep their original voice.
    - Move the Q1 emitter rework into its own subsection, and put the
    transistor-destroying caution before the steps instead of after them
    - Split the rework checks, leg identification and meter verification into lists
    - No semicolons, contractions or Latin abbreviations in the rewritten sections
    - Code blocks, inline code, link targets and HTML verified unchanged; the only
    additions are the new heading and one link to it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
2026-09-18 docs: rewrite the advisory and the PCBWay assembly doc in the style of Simplified Technical English
    Same tiering as the README pass. Procedures and warnings follow the ASD-STE100
    procedural rules. Descriptive sections follow the structural rules. Root-cause
    analysis, the risk narrative, method and limits notes, DFM rationale and credits
    keep their original voice.
    SAFETY-ADVISORY-2026-09-vbus-trace-ampacity.md
    - Rework options become numbered imperative steps, conditions before commands
    - "Do not fit a lower-rated fuse" promoted into a CAUTION block
    - No progressive tense or colon splices in the "What is wrong" section
    - British spellings normalized to American for consistency with the READM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
2026-09-24 docs: undo the stiffest STE phrasing in the README
    The STE pass left a lot of choppy, over-literal sentences ("It has its own
    users", "Look at this band when you assemble by hand", "Each derivative
    needs its own certification" after three one-clause sentences). Rejoin the
    fragments, use contractions and normal idiom, and keep every number, part
    number, link and warning unchanged.
2026-09-24 docs: undo the stiffest STE phrasing in the advisory and assembly doc
    Same treatment as the README in #20: join the one-clause sentences back
    together and swap literal phrasings ("For step 3 you have two methods",
    "obey these precautions", "The answer in both cases is the instruction
    above") for normal English. Numbers, part numbers and warnings are
    unchanged.
    Also fixes the TPS2552/TPS2553 line, which read "The 2-against-3 digit is
    active-high against active-low enable". That pairs 2 with active-high,
    but the TPS2552 is active-low and the TPS2553 is active-high.
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
